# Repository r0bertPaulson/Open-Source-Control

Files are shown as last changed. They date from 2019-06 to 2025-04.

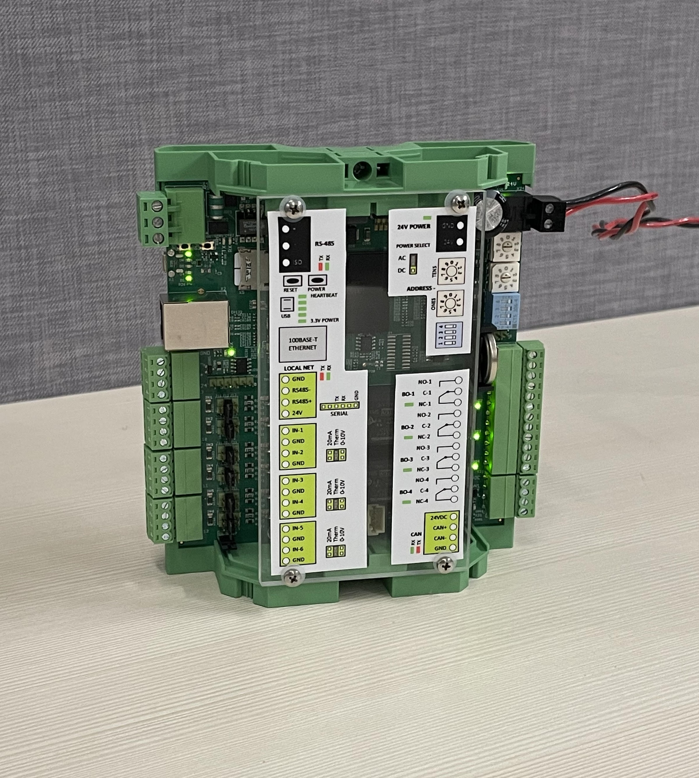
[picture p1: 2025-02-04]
Version_3.0/Open_Source_Controller_C663x+.jpg

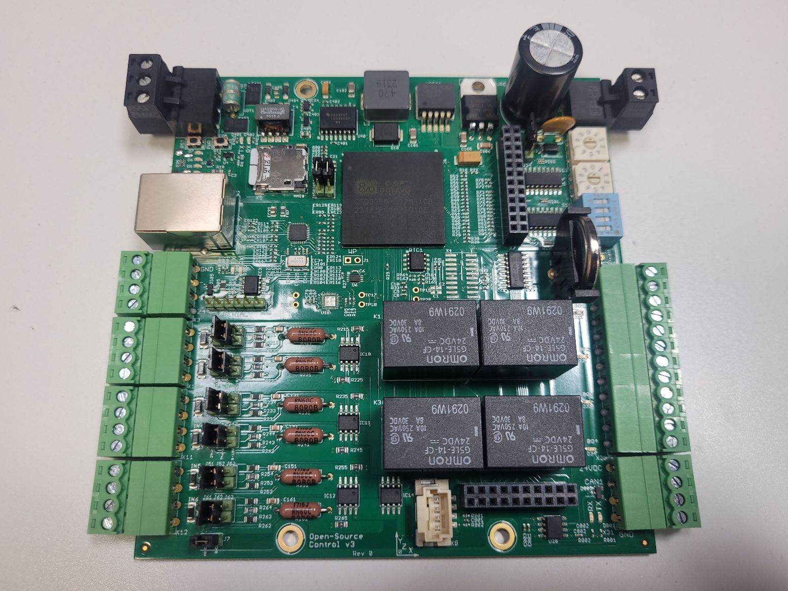
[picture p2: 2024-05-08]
Version_3.0/Open Source Controller V3.jpg

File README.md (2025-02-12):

# Open-Source-Control
Collection of Open Source IoT Designs

-Unitary Controller Version 3.0 - This device will be suitable for control of automated and networked building equipment at the unitary level. For example, you could control a single airconditioner unit with this device.

Project Status:
1.	Use Version 3.0 - Full BOM and Academic Free License statement to be posted here shortly.

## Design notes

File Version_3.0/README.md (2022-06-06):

New Modular Board which allows the creation of a family of devices to cover most Building Automation control use cases. 

This board will have headers that can connect to an add-on sub-board and other devices that are application specific.

For example, by adding an airflow sensor and two analog actuator outputs, you will have a device that can control a VAV (Variable Air Volume) terminal unit specifically.

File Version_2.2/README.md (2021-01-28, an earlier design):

Low Scale Prototype/Pre-Production Version. Minor hardware changes to occur as software dictates.

Adding the ability to connect main RS-485 tx/rx to either UART4 or PRU1_UART0. The PRU UART0 would be good to offload communication overhead of token-based network protocols from the main processor. Cleaning up layout and power planes for improved signal integrity.

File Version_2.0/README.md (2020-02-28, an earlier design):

DO NOT USE THIS DESIGN EITHER. FOR REFERENCE ONLY.

Prototype was made and tested. Board was mostly functional, but improvements and fixes have been made in 2.1+

Please Use Version 2.1+

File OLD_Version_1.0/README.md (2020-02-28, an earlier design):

DO NOT USE THIS DESIGN. PROTOTYPE HAS NOT BEEN MADE OR TESTED. FOR REFERENCE ONLY. 

Please Use Version 2.1+

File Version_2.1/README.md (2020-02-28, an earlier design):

Version 2.1

Testing shows that boards 2.1 and above are largely functional and are recommend for prototyping. Version 2.0 and below should not be used or built and are for reference only.

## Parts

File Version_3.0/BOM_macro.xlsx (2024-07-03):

Designator | Value | Footprint | Populate | MPN | Manufacturer | MPN | Manufacturer
C1 | DNI | C0603 | 0
C10 | 0.1uF, 6.3V | C0402 | 1 | GRM155R70J104KA01D | Murata
C100 | 1000uF, 50V, UHE1H102MHD6 | PCAP_16X25-THRU-ELECT | 0 | UHE1H102MHD6 | Nichicon
C101 | 0.47uF, 100V, X7R | 1206 | 1 | HMK316B7474KL-T | Taiyo Yuden
C102 | 0.47uF, 100V, X7R | 1206 | 1 | HMK316B7474KL-T | Taiyo Yuden
C104 | 0.1uF, 6.3V | C0402 | 1 | GRM155R70J104KA01D | Murata
C105 | 0.47uF, 100V, X7R | 1206 | 1 | HMK316B7474KL-T | Taiyo Yuden
C106 | 0.1uF, 50V | 1206 | 1 | C1206C104J5RACTU | KEMET
C11 | 220uF, 6.3V, T491C227K006AT | C/6032-28R | 1 | T491C227K006AT | KEMET
C111 | 1uF | C0805 | 1 | MF-CAP-0805-1uF | MacroFab
C121 | 1uF | C0805 | 1 | MF-CAP-0805-1uF | MacroFab
C131 | 1uF | C0805 | 1 | MF-CAP-0805-1uF | MacroFab
C14 | 0.1uF, 6.3V | C0402 | 1 | GRM155R70J104KA01D | Murata
C141 | 1uF | C0805 | 1 | MF-CAP-0805-1uF | MacroFab
C15 | 0.1uF, 6.3V | C0402 | 1 | GRM155R70J104KA01D | Murata
C151 | 1uF | C0805 | 1 | MF-CAP-0805-1uF | MacroFab
C161 | 1uF | C0805 | 1 | MF-CAP-0805-1uF | MacroFab
C2 | DNI | C0603 | 0
C21 | 10uF, 10V | C0805 | 1 | LMK212BJ106KG-T | Taiyo Yuden
C22 | 0.1uF, 6.3V | C0402 | 1 | GRM155R70J104KA01D | Murata
C3 | 0.1uF, 6.3V | C0402 | 1 | GRM155R70J104KA01D | Murata
C301 | 0.1uF, 6.3V | C0402 | 1 | GRM155R70J104KA01D | Murata
C4 | 47uF | C0805 | 1 | GRT21BR60J476ME13L | Murata
C401 | 0.1uF, 16V | C0402 | 1 | MF-CAP-0402-0.1uF | MacroFab
C402 | 0.1uF, 16V | C0402 | 1 | MF-CAP-0402-0.1uF | MacroFab
C403 | 0.1uF, 16V | C0402 | 1 | MF-CAP-0402-0.1uF | MacroFab
C404 | 10uF, 16V | C0805 | 1 | C0805C106K4PACTU | KEMET
C405 | 10uF, 16V | C0805 | 1 | C0805C106K4PACTU | KEMET
C406 | 4.7uF, 16V, T491A475K016AT | A/3216-18R | 1 | T491A475K016AT | KEMET
C6 | 0.1uF, 6.3V | C0402 | 1 | GRM155R70J104KA01D | Murata
C79 | 0.1uF, 6.3V | C0402 | 1 | GRM155R70J104KA01D | Murata
C8 | 1nF | C0402 | 1 | MF-CAP-0402-1nF | MacroFab
C801 | 0.1uF, 6.3V | C0402 | 1 | GRM155R70J104KA01D | Murata
C802 | 0.1uF, 6.3V | C0402 | 1 | GRM155R70J104KA01D | Murata
C803 | 4.7uF, 6.3V | C0402 | 1 | GRM155R60J475ME47D | Murata
C85 | 2200pF, 6.3V | C0402 | 1 | C0402C222K9RAC7867 | KEMET
C87 | 2200pF, 6.3V | C0402 | 1 | C0402C222K9RAC7867 | KEMET
C88 | 2200pF, 6.3V | C0402 | 1 | C0402C222K9RAC7867 | KEMET
C9 | 0.1uF, 6.3V | C0402 | 1 | GRM155R70J104KA01D | Murata
C901 | 0.1uF, 6.3V | C0402 | 1 | GRM155R70J104KA01D | Murata
D1 | LTST-C191KGKT | EIA-STD | 1 | LTST-C191KGKT | Lite-On
D18 | B550C-13-F | SMC | 1 | B550C-13-F | Diodes Inc.
D19 | LTST-C191KGKT | EIA-STD | 1 | LTST-C191KGKT | Lite-On
D3 | S1D | SMA | 1 | S1D | onsemi
D301 | LTST-C191KRKT | EIA-STD | 1 | LTST-C191KRKT | Lite-On
D302 | LTST-C191KGKT | EIA-STD | 1 | LTST-C191KGKT | Lite-On
D305 | SM712 | SOT23-3 | 1 | SM712-02HTG | Littelfuse
D31 | LTST-C191KGKT | EIA-STD | 1 | LTST-C191KGKT | Lite-On
D32 | LTST-C191KGKT | EIA-STD | 1 | LTST-C191KGKT | Lite-On
D33 | LTST-C191KGKT | EIA-STD | 1 | LTST-C191KGKT | Lite-On
D34 | LTST-C191KGKT | EIA-STD | 1 | LTST-C191KGKT | Lite-On
D4 | LTST-C191KGKT | EIA-STD | 1 | LTST-C191KGKT | Lite-On
D401 | LTST-C191KRKT | EIA-STD | 1 | LTST-C191KRKT | Lite-On
D402 | LTST-C191KGKT | EIA-STD | 1 | LTST-C191KGKT | Lite-On
D403 | MBR0520LT | SOD123 | 1 | MBR0520LT1G | onsemi
D404 | MBR0520LT | SOD123 | 1 | MBR0520LT1G | onsemi
D405 | SM712 | SOT23-3 | 1 | SM712-02HTG | Littelfuse
D5 | LTST-C191KGKT | EIA-STD | 1 | LTST-C191KGKT | Lite-On
D6 | LTST-C191KGKT | EIA-STD | 1 | LTST-C191KGKT | Lite-On
D7 | LTST-C191KGKT | EIA-STD | 1 | LTST-C191KGKT | Lite-On
D801 | LTST-C191KRKT | EIA-STD | 1 | LTST-C191KRKT | Lite-On
D802 | LTST-C191KGKT | EIA-STD | 1 | LTST-C191KGKT | Lite-On
D805 | CDSOT23-T24CAN | SOT23-3 | 1 | CDSOT23-T24CAN | Bourns
EC30 | 0.1uF, 6.3V | C0402 | 1 | GRM155R70J104KA01D | Murata
EC31 | 0.1uF, 6.3V | C0402 | 1 | GRM155R70J104KA01D | Murata
EC32 | 10uF, 10V | C0805 | 1 | LMK212BJ106KG-T | Taiyo Yuden
EC33 | 1uF, 10V | C0402 | 1 | C0402C105K8PACTU | KEMET
EC34 | 0.1uF, 6.3V | C0402 | 1 | GRM155R70J104KA01D | Murata
EC35 | 470pF, 6.3V | C0402 | 1 | C0402C471K9RACTU | KEMET
EC36 | 15pF, DNI | C0402 | 0
EC37 | 15pF, DNI | C0402 | 0
EC38 | 15pF, DNI | C0402 | 0
EC39 | 15pF, DNI | C0402 | 0
EC40 | 0.022uF, 10V | C0402 | 1 | C0402C223K8PACTU | KEMET
EC41 | 30pF, 50V | C0402 | 1 | GJM1555C1H300FB01D | Murata
EC42 | 30pF, 50V | C0402 | 1 | GJM1555C1H300FB01D | Murata
ER100 | 1.5K, 1% | R0402 | 1 | ERJPA2F1501X | Panasonic
ER101 | 10K, 1% | R0402 | 1 | RC0402FR-0710KL | Yageo
ER102 | 10K, 1% | R0402 | 1 | RC0402FR-0710KL | Yageo
ER103 | 10K, 1% | R0402 | 1 | RC0402FR-0710KL | Yageo
ER104 | 10K, 1% | R0402 | 1 | RC0402FR-0710KL | Yageo
ER105 | 1.5K, 1% | R0402 | 1 | ERJPA2F1501X | Panasonic
ER106 | 49.9, 1% | R0402 | 1 | RC0402FR-0749R9L | Yageo
ER107 | 49.9, 1% | R0402 | 1 | RC0402FR-0749R9L | Yageo
ER108 | 49.9, 1% | R0402 | 1 | RC0402FR-0749R9L | Yageo
ER109 | 49.9, 1% | R0402 | 1 | RC0402FR-0749R9L | Yageo
ER110 | 100, 1% | R0402 | 1 | RC0402FR-07100RL | Yageo
ER111 | 100, 1% | R0402 | 1 | RC0402FR-07100RL | Yageo
ER112 | 100, 1% | R0402 | 1 | RC0402FR-07100RL | Yageo
ER113 | 100, 1% | R0402 | 1 | RC0402FR-07100RL | Yageo
ER114 | 100, 1% | R0402 | 1 | RC0402FR-07100RL | Yageo
ER115 | 470, 1% | R0402 | 1 | RC0402FR-13470RL | Yageo
ER116 | 100, 1% | R0402 | 1 | RC0402FR-07100RL | Yageo
ER117 | 470, 1% | R0402 | 1 | RC0402FR-13470RL | Yageo
ER118 | 100, 1% | R0402 | 1 | RC0402FR-07100RL | Yageo
ER119 | 100, 1% | R0402 | 1 | RC0402FR-07100RL | Yageo
ER120 | 10K, 1% | R0402 | 1 | RC0402FR-0710KL | Yageo
ER122 | 0, 1% | R0402 | 1 | RC0402FR-070RL | Yageo
ER123 | 100, 1% | R0402 | 1 | RC0402FR-07100RL | Yageo
ER124 | 100, 1% | R0402 | 1 | RC0402FR-07100RL | Yageo
ER125 | 1M, 1%, DNI | R0402 | 0
ER126 | 0, 1% | R0402 | 1 | RC0402FR-070RL | Yageo
ER127 | 10, 1% | R0402 | 1 | RC0402FR-0710RL | Yageo
ER128 | 12.1K, 1% | R0402 | 1 | ERJ-2RKF1212X | Panasonic
ER129 | 10K, 1% | R0402 | 1 | RC0402FR-0710KL | Yageo
ER98 | 1.5K, 1% | R0402 | 1 | ERJPA2F1501X | Panasonic
ER99 | 1.5K, 1% | R0402 | 1 | ERJPA2F1501X | Panasonic
F1 | 60V, 750mA, R075 | PTH | 0 | MF-R075-99 | Bourns
F401 | TBU-CA085-300-WH | TBU-CA | 1 | TBU-CA085-300-WH | Bourns
F402 | TBU-CA085-300-WH | TBU-CA | 1 | TBU-CA085-300-WH | Bourns
FB7 | 150ohm, 800mA | C0805 | 1 | MU2029-151Y | Bourns
FUD1 | FIDUCIAL | FIDUCIAL_40MIL | 0
FUD2 | FIDUCIAL | FIDUCIAL_40MIL | 0
FUD3 | FIDUCIAL | FIDUCIAL_40MIL | 0
FUD4 | FIDUCIAL | FIDUCIAL_40MIL | 0
FUD5 | FIDUCIAL | FIDUCIAL_40MIL | 0
FUD6 | FIDUCIAL | FIDUCIAL_40MIL | 0
G1 | CR2032V | CR2032V | 0
GDT1 | 2036-07-B3 | 2036-XX-B3 | 0 | 2036-07-B3 | Bourns
IC10 | MCP6002SMT | SOIC8 | 1 | MCP6002T-E/SN | Microchip
IC11 | MCP6002SMT | SOIC8 | 1 | MCP6002T-E/SN | Microchip
IC12 | MCP6002SMT | SOIC8 | 1 | MCP6002T-E/SN | Microchip
IC14 | MCP6002SMT | SOIC8 | 1 | MCP6002T-E/SN | Microchip
IC2 | ULN2003AD | SO16 | 1 | ULN2003AD | Texas Instruments
IC4 | 74HC165D | SO16 | 1 | 74HC165D | Toshiba | SN74HC165DR | Texas Instruments
IC5 | 74HC165D | SO16 | 1 | 74HC165D | Toshiba | SN74HC165DR | Texas Instruments
J1 |  | H2-2.54 | 0
J11 |  | H2-2.54 | 0
J12 |  | H2-2.54 | 0
J13 |  | H2-2.54 | 0
J21 |  | H2-2.54 | 0
J22 |  | H2-2.54 | 0
J23 |  | H2-2.54 | 0
J24 | 6p-2.54 | H3-2.54 | 0 | P125-1106A1BS116A1 | YXCON
J3 |  | H2-2.54 | 0
J31 |  | H2-2.54 | 0
J32 |  | H2-2.54 | 0
J33 |  | H2-2.54 | 0
J41 |  | H2-2.54 | 0
J42 |  | H2-2.54 | 0
J43 |  | H2-2.54 | 0
J45 |  | H2-2.54 | 0
J450 |  | H2-2.54 | 0
J454 |  | H2-2.54 | 0
J51 |  | H2-2.54 | 0
J52 |  | H2-2.54 | 0
J53 |  | H2-2.54 | 0
J61 |  | H2-2.54 | 0
J62 |  | H2-2.54 | 0
J63 |  | H2-2.54 | 0
J7 |  | H2-2.54 | 0
K1 | G5LE-14-CF DC24 | JS-M | 0 | G5LE-14-CF DC24 | Omron
K2 | G5LE-14-CF DC24 | JS-M | 0 | G5LE-14-CF DC24 | Omron
K3 | G5LE-14-CF DC24 | JS-M | 0 | G5LE-14-CF DC24 | Omron
K4 | G5LE-14-CF DC24 | JS-M | 0 | G5LE-14-CF DC24 | Omron
L2 | SRP1265A-470M | SRP1265 | 1 | SRP1265A-470M | Bourns
MTG1 | MOUNT-PAD-ROUND3.6 | 3,6-PAD | 0
MTG2 | MOUNT-PAD-ROUND3.6 | 3,6-PAD | 0
MTG3 | MOUNT-PAD-ROUND3.6 | 3,6-PAD | 0
MTG4 | MOUNT-PAD-ROUND3.6 | 3,6-PAD | 0
Q1 | MMBT2907 | SOT23-BEC | 1 | MMBT2907ALT1G | onsemi
R10 | 0, 1% | R0805 | 1 | ERJ-6GEY0R00V | Panasonic
R11 | 0 | R0402 | 1 | MF-RES-0402-0 | MacroFab
R12 | 1.5K, 1% | R0402 | 1 | ERJPA2F1501X | Panasonic
R13 | 1.5K, 1% | R0402 | 1 | ERJPA2F1501X | Panasonic
R15 | 40.2K | R0402 | 1 | RC0402FR-0740K2L | Yageo
R163 | 100K, DNI | R0402 | 0
R164 | 1.5K, 1% | R0402 | 1 | ERJPA2F1501X | Panasonic
R168 | 10K | R0402 | 1 | MF-RES-0402-10K | MacroFab
R169 | 10K, 1% | R0402 | 1 | RC0402FR-0710KL | Yageo
R170 | 10K, 1% | R0402 | 1 | RC0402FR-0710KL | Yageo
R171 | 10K | R0402 | 1 | MF-RES-0402-10K | MacroFab
R172 | 10K | R0402 | 1 | MF-RES-0402-10K | MacroFab
R173 | 10K | R0402 | 1 | MF-RES-0402-10K | MacroFab
R174 | 10K | R0402 | 1 | MF-RES-0402-10K | MacroFab
R18 | 4.75K, 1% | R0402 | 1 | RC0402FR-074K75L | Yageo
R181 | B72520T0300K062 | CT/CN1206 | 1 | B72520T0300K062 | EPCOS
R182 | B72520T0300K062 | CT/CN1206 | 1 | B72520T0300K062 | EPCOS
R183 | B72520T0300K062 | CT/CN1206 | 1 | B72520T0300K062 | EPCOS
R184 | B72520T0300K062 | CT/CN1206 | 1 | B72520T0300K062 | EPCOS
R185 | B72520T0300K062 | CT/CN1206 | 1 | B72520T0300K062 | EPCOS
R186 | B72520T0300K062 | CT/CN1206 | 1 | B72520T0300K062 | EPCOS
R20 | 10K | R0402 | 1 | MF-RES-0402-10K | MacroFab
R21 | 499 | R0402 | 1 | RC0402FR-07499RL | Yageo
R211 | 80, 0.1% | 0309/12 | 0 | CMF6080R000BEBF | Vishay
R212 | 10K, 1% | R0805 | 1 | CRCW080510K0FKEB | Vishay
R213 | 2K, 1% | R0805 | 1 | ERJ-6ENF2001V | Panasonic
R214 | 10K, 1% | R0805 | 1 | CRCW080510K0FKEB | Vishay
R215 | 100K | R0805 | 1 | MF-RES-0805-100K | MacroFab
R22 | 4.75K, 1% | R0402 | 1 | RC0402FR-074K75L | Yageo
R221 | 80, 0.1% | 0309/12 | 0 | CMF6080R000BEBF | Vishay
R222 | 10K, 1% | R0805 | 1 | CRCW080510K0FKEB | Vishay
R223 | 2K, 1% | R0805 | 1 | ERJ-6ENF2001V | Panasonic
R224 | 10K, 1% | R0805 | 1 | CRCW080510K0FKEB | Vishay
R225 | 100K | R0805 | 1 | MF-RES-0805-100K | MacroFab
R231 | 80, 0.1% | 0309/12 | 0 | CMF6080R000BEBF | Vishay
R232 | 10K, 1% | R0805 | 1 | CRCW080510K0FKEB | Vishay
R233 | 2K, 1% | R0805 | 1 | ERJ-6ENF2001V | Panasonic
R234 | 10K, 1% | R0805 | 1 | CRCW080510K0FKEB | Vishay
R235 | 100K | R0805 | 1 | MF-RES-0805-100K | MacroFab
R241 | 80, 0.1% | 0309/12 | 0 | CMF6080R000BEBF | Vishay
R242 | 10K, 1% | R0805 | 1 | CRCW080510K0FKEB | Vishay
R243 | 2K, 1% | R0805 | 1 | ERJ-6ENF2001V | Panasonic
R244 | 10K, 1% | R0805 | 1 | CRCW080510K0FKEB | Vishay
R245 | 100K | R0805 | 1 | MF-RES-0805-100K | MacroFab
R25 | 0, 1% | R0402 | 1 | RC0402FR-070RL | Yageo
R251 | 80, 0.1% | 0309/12 | 0 | CMF6080R000BEBF | Vishay
R252 | 10K, 1% | R0805 | 1 | CRCW080510K0FKEB | Vishay
R253 | 2K, 1% | R0805 | 1 | ERJ-6ENF2001V | Panasonic
R254 | 10K, 1% | R0805 | 1 | CRCW080510K0FKEB | Vishay
R255 | 100K | R0805 | 1 | MF-RES-0805-100K | MacroFab
R26 | 1.5K, 1% | R0402 | 1 | ERJPA2F1501X | Panasonic
R261 | 80, 0.1% | 0309/12 | 0 | CMF6080R000BEBF | Vishay
R262 | 10K, 1% | R0805 | 1 | CRCW080510K0FKEB | Vishay
R263 | 2K, 1% | R0805 | 1 | ERJ-6ENF2001V | Panasonic
R264 | 10K, 1% | R0805 | 1 | CRCW080510K0FKEB | Vishay
R265 | 100K | R0805 | 1 | MF-RES-0805-100K | MacroFab
R27 | 100K, 1% | R0402 | 1 | RC0402FR-07100KL | Yageo
R28 | 0, 1% | R0402 | 1 | RC0402FR-070RL | Yageo
R281 | 10K | RN0804 | 1 | YC124-JR-0710KL | Yageo
R282 | 10K | RN0804 | 1 | YC124-JR-0710KL | Yageo
R29 | 0, 1% | R0402 | 1 | RC0402FR-070RL | Yageo
R291 | 10K | RN0804 | 1 | YC124-JR-0710KL | Yageo
R3 | 0, 1% | R0402 | 1 | RC0402FR-070RL | Yageo
R30 | 0, 1% | R0402 | 1 | RC0402FR-070RL | Yageo
R301 | 1K | R0402 | 1 | MF-RES-0402-1K | MacroFab
R302 | 1K | R0402 | 1 | MF-RES-0402-1K | MacroFab
R303 | 1K, DNI | R0402 | 0
R304 | 1K, DNI | R0402 | 0
R305 | 150, 1% | R0805 | 1 | CRCW0805150RFKEAHP | Vishay
R31 | 22, 1% | R0402 | 1 | RC0402FR-0722RL | Yageo
R33 | 0, 1% | R0402 | 1 | RC0402FR-070RL | Yageo
R34 | .1, 0805 | R0805 | 1 | CRL0805-FW-R100ELF | Bourns
R35 | 1K | RN0804 | 1 | YC124-JR-071KL | Yageo
R39 | 4.75K, 1% | R0402 | 1 | RC0402FR-074K75L | Yageo
R4 | 0, 1% | R0402 | 1 | RC0402FR-070RL | Yageo
R40 | 4.75K, 1% | R0402 | 1 | RC0402FR-074K75L | Yageo
R401 | 1K | R0402 | 1 | MF-RES-0402-1K | MacroFab
R402 | 1K | R0402 | 1 | MF-RES-0402-1K | MacroFab
R41 | 4.75K, 1% | R0402 | 1 | RC0402FR-074K75L | Yageo
R5 | 0 | R0402 | 1 | MF-RES-0402-0 | MacroFab
R53 | 100K, 1% | R0402 | 1 | RC0402FR-07100KL | Yageo
R54 | 100K, 1%, DNI | R0402 | 0
R55 | 100K, 1% | R0402 | 1 | RC0402FR-07100KL | Yageo
R56 | 100K, 1% | R0402 | 1 | RC0402FR-07100KL | Yageo
R57 | 100K, 1% | R0402 | 1 | RC0402FR-07100KL | Yageo
R58 | 100K, 1% | R0402 | 1 | RC0402FR-07100KL | Yageo
R59 | 100K, 1% | R0402 | 1 | RC0402FR-07100KL | Yageo
R6 | 100K, DNI | R0402 | 0
R60 | 100K, 1% | R0402 | 1 | RC0402FR-07100KL | Yageo
R61 | 100K, 1% | R0402 | 1 | RC0402FR-07100KL | Yageo
R62 | 100K, 1% | R0402 | 1 | RC0402FR-07100KL | Yageo
R63 | 100K, 1% | R0402 | 1 | RC0402FR-07100KL | Yageo
R64 | 100K, 1%, DNI | R0402 | 0
R65 | 100K, 1%, DNI | R0402 | 0
R66 | 100K, 1%, DNI | R0402 | 0
R67 | 100K, 1% | R0402 | 1 | RC0402FR-07100KL | Yageo
R68 | 100K, 1% | R0402 | 1 | RC0402FR-07100KL | Yageo
R69 | 100, 1% | R0402 | 1 | RC0402FR-07100RL | Yageo
R70 | 100K, 1%, DNI | R0402 | 0
R71 | 100K, 1% | R0402 | 1 | RC0402FR-07100KL | Yageo
R72 | 100K, 1%, DNI | R0402 | 0
R73 | 100K, 1%, DNI | R0402 | 0
R74 | 100K, 1%, DNI | R0402 | 0
R75 | 100K, 1%, DNI | R0402 | 0
R76 | 100K, 1%, DNI | R0402 | 0
R77 | 100K, 1%, DNI | R0402 | 0
R78 | 100K, 1%, DNI | R0402 | 0
R79 | 100K, 1%, DNI | R0402 | 0
R8 | 1K | R0402 | 1 | MF-RES-0402-1K | MacroFab
R80 | 100K, 1%, DNI | R0402 | 0
R801 | 1K | R0402 | 1 | MF-RES-0402-1K | MacroFab
R802 | 1K | R0402 | 1 | MF-RES-0402-1K | MacroFab
R81 | 100K, 1% | R0402 | 1 | RC0402FR-07100KL | Yageo
R82 | 100K, 1% | R0402 | 1 | RC0402FR-07100KL | Yageo
R83 | 100K, 1% | R0402 | 1 | RC0402FR-07100KL | Yageo
R84 | 100K, 1%, DNI | R0402 | 0
R85 | 100K, 1%, DNI | R0402 | 0
R86 | 10K, 1% | R0402 | 1 | RC0402FR-0710KL | Yageo
R87 | 10K, 1% | R0402 | 1 | RC0402FR-0710KL | Yageo
R88 | 10K, 1% | R0402 | 1 | RC0402FR-0710KL | Yageo
R89 | 10K, 1% | R0402 | 1 | RC0402FR-0710KL | Yageo
R90 | 10K, 1% | R0402 | 1 | RC0402FR-0710KL | Yageo
R901 | 1.5K, 1% DNI | R0402 | 0
R902 | 1.5K, 1% DNI | R0402 | 0
R91 | 10K, 1% | R0402 | 1 | RC0402FR-0710KL | Yageo
R92 | 10K, 1% | R0402 | 1 | RC0402FR-0710KL | Yageo
RTC1 | DS3231MZ+ | SO08 | 1 | DS3231MZ+ | Analog Devices
S1 | KMR231GLFS | SW4SMD_63X161LS | 1 | KMR233GLFG | C&K Components
S11 |  | P101 | 1 | 94HAB10T | Grayhill
S12 |  | P101 | 1 | 94HAB10T | Grayhill
S13 |  | DS-04 | 1 | 206-4LPST | CTS Components
S2 | KMR231GLFS | SW4SMD_63X161LS | 1 | KMR233GLFG | C&K Components
T4 | DA2304-AL | DA230X-AL | 1 | DA2304-AL | Coilcraft
TP1 | TPB0,65 | TP_B0,65 | 0
TP10 | TESTPAD/W_HOLE_1X1 | TESTPAD/W_HOLE_1X1 | 0
TP11 | TPB0,65 | TP_B0,65 | 0
TP12 | TPB0,65 | TP_B0,65 | 0
TP13 | TPB0,65 | TP_B0,65 | 0
TP14 | TPB0,65 | TP_B0,65 | 0
TP15 | TPB0,65 | TP_B0,65 | 0
TP16 | TPB0,65 | TP_B0,65 | 0
TP17 | TESTPAD/W_HOLE_1X1 | TESTPAD/W_HOLE_1X1 | 0
TP18 | TESTPAD/W_HOLE_1X1 | TESTPAD/W_HOLE_1X1 | 0
TP19 | TESTPAD/W_HOLE_1X1 | TESTPAD/W_HOLE_1X1 | 0
TP2 | TPB0,65 | TP_B0,65 | 0
TP20 | TESTPAD/W_HOLE_1X1 | TESTPAD/W_HOLE_1X1 | 0
TP21 | TPB0,65 | TP_B0,65 | 0
TP22 | TPB0,65 | TP_B0,65 | 0
TP23 | TPB0,65 | TP_B0,65 | 0
TP24 | TPB0,65 | TP_B0,65 | 0
TP26 | TPB0,65 | TP_B0,65 | 0
TP3 | TPB0,65 | TP_B0,65 | 0
TP31 | TPB0,65 | TP_B0,65 | 0
TP32 | TPB0,65 | TP_B0,65 | 0
TP33 | TPB0,65 | TP_B0,65 | 0
TP4 | TPB0,65 | TP_B0,65 | 0
TP5 | TESTPAD/W_HOLE_1X1 | TESTPAD/W_HOLE_1X1 | 0
TP6 | TESTPAD/W_HOLE_1X1 | TESTPAD/W_HOLE_1X1 | 0
TP7 | TESTPAD/W_HOLE_1X1 | TESTPAD/W_HOLE_1X1 | 0
TP8 | TESTPAD/W_HOLE_1X1 | TESTPAD/W_HOLE_1X1 | 0
TP9 | TESTPAD/W_HOLE_1X1 | TESTPAD/W_HOLE_1X1 | 0
U$2 |  | XYZ-LABEL | 0
U1 | OSD3358-512M-ICB | OSD335X-BGA-400 | 1 | OSD3358-512M-ICB | Octavo Systems
U16 | AT97SC3205T-G3M4400B | QFN32-0.4-4X4MM | 0 | AT97SC3205T-G3M4400B | Microchip
U2 | TPD4S012_DRY_6_P1_M | DRY6 | 1 | TPD4S012DRYR | Texas Instruments
U27 | LAN8710 | LAN8710A-QFN32 | 1 | LAN8710AI-EZK | Microchip
U28 | TCAN1051HV | BEAGLEBONE_BLUE_D8 | 1 | TCAN1051HVDR | Texas Instruments
U29 | MAX3483EESA+T | 21-0041B_8 | 1 | MAX3483EESA+T | Analog Devices
U4 | APX811-31UGSOT | SOT143-R | 1 | APX811-31UG-7 | Diodes Inc.
U40 | ISO3086TDW | DW16 | 1 | ISO3086TDW | Texas Instruments
U5 | TLVH431 | SOT23-3 | 1 | TLVH431IDBZR | Texas Instruments
U6 | SN74LVC2G241_DCU_8 | DCU8 | 1 | SN74LVC2G241DCUT | Texas Instruments
VREG1 | LM2596S-5.0 | TO263-5 | 1 | LM2596S-5.0 | Texas Instruments | LM2596S-5.0/NOPB | Texas Instruments
VREG2 | L7824CV | 78XXL | 1 | L7824CV-DG | STMicroelectronics
VREG4 | TPS76350 | DBV5 | 1 | TPS76350DBVR | Texas Instruments
X1 | 10118194-0001LF | 10118194-0001LF(MICRO-USB-B-AMPHENOL-FCI) | 1 | 10118194-0001LF | Amphenol Communications Solutions
X10 | MC4 | MC4 | 1 | ECH381R-04P | Dinkle
X11 | MC4 | MC4 | 1 | ECH381R-04P | Dinkle
X12 | MC4 | MC4 | 1 | ECH381R-04P | Dinkle
X2 | J0011D01BNL | J0011D01BNL | 1 | J0011D01BNL | Pulse
X21 | MC12 | MC12 | 1 | ECH381R-12P | Dinkle
X24 | MSTBA2 | MSTBA2 | 1 | 2EHDRC-02P-BK | Dinkle | 2EHDRC-02P | Dinkle
X3 | MC4 | MC4 | 1 | ECH381R-04P | Dinkle
X31 | MC4 | MC4 | 1 | ECH381R-04P | Dinkle
X4 | CTI-JTAG | CTI-JTAG | 0
X41 | MSTBA3 | MSTBA3 | 1 | 2EHDRC-03P | Dinkle
X5 | DM3CS-SF | DM3CS-SF | 1 | DM3CS-SF | HIROSE ELECTRIC
X6 | 6p-2.54 | H6-2.54 | 0 | P125-1106A1BS116A1 | YXCON
X7 | TH-2X10 | H2X10-2.54 | 0
X8 | TH-2X10 | H2X10-2.54 | 0
X9 | 5600200420 | 5600200420 | 1 | 560020-0420 | Molex
Y7 | ECS-250-12-30-GN-TR | XTAL_2-SMD(5X3.2MM) | 1 | ECS-250-12-30-GN-TR | ECS International

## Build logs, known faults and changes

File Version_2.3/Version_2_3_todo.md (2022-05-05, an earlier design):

Version 2.3 To Do:

1) Create I2C connection for Sensirion Air Flow Sensor by adding Molex Plugable Terminal PN 5023520400
	or 5600200420 (vertical mount).
2) Create connection for Analog Output Add-On board.
3) Replace 5V Regulator Power Inductor (L2) with Bourns PN SRP1265A-470M. {DONE}
4) Find alternate compatible crystal for Ethernet Phy. ABM3-25.000MHZ-J2Y-T (also used for Micrel) 
	or alternatively use the direct replacement from Digikey ECS-250-12-30-GN-TR? {DONE}
5) Update Crystal Footprint and device (Y7) with generic 5x3.2mm 2-SMD {DONE}  
5) Change Relay Output terminal blocks to 12 position version with C, N.O. and N.C. terminals.
6) Add capability for add-on Relay HOA board.
7) Update Relay part number to G5LE due to JS1 EOL. {DONE}

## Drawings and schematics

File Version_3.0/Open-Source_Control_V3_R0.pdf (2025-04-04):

# Power & Reset

A

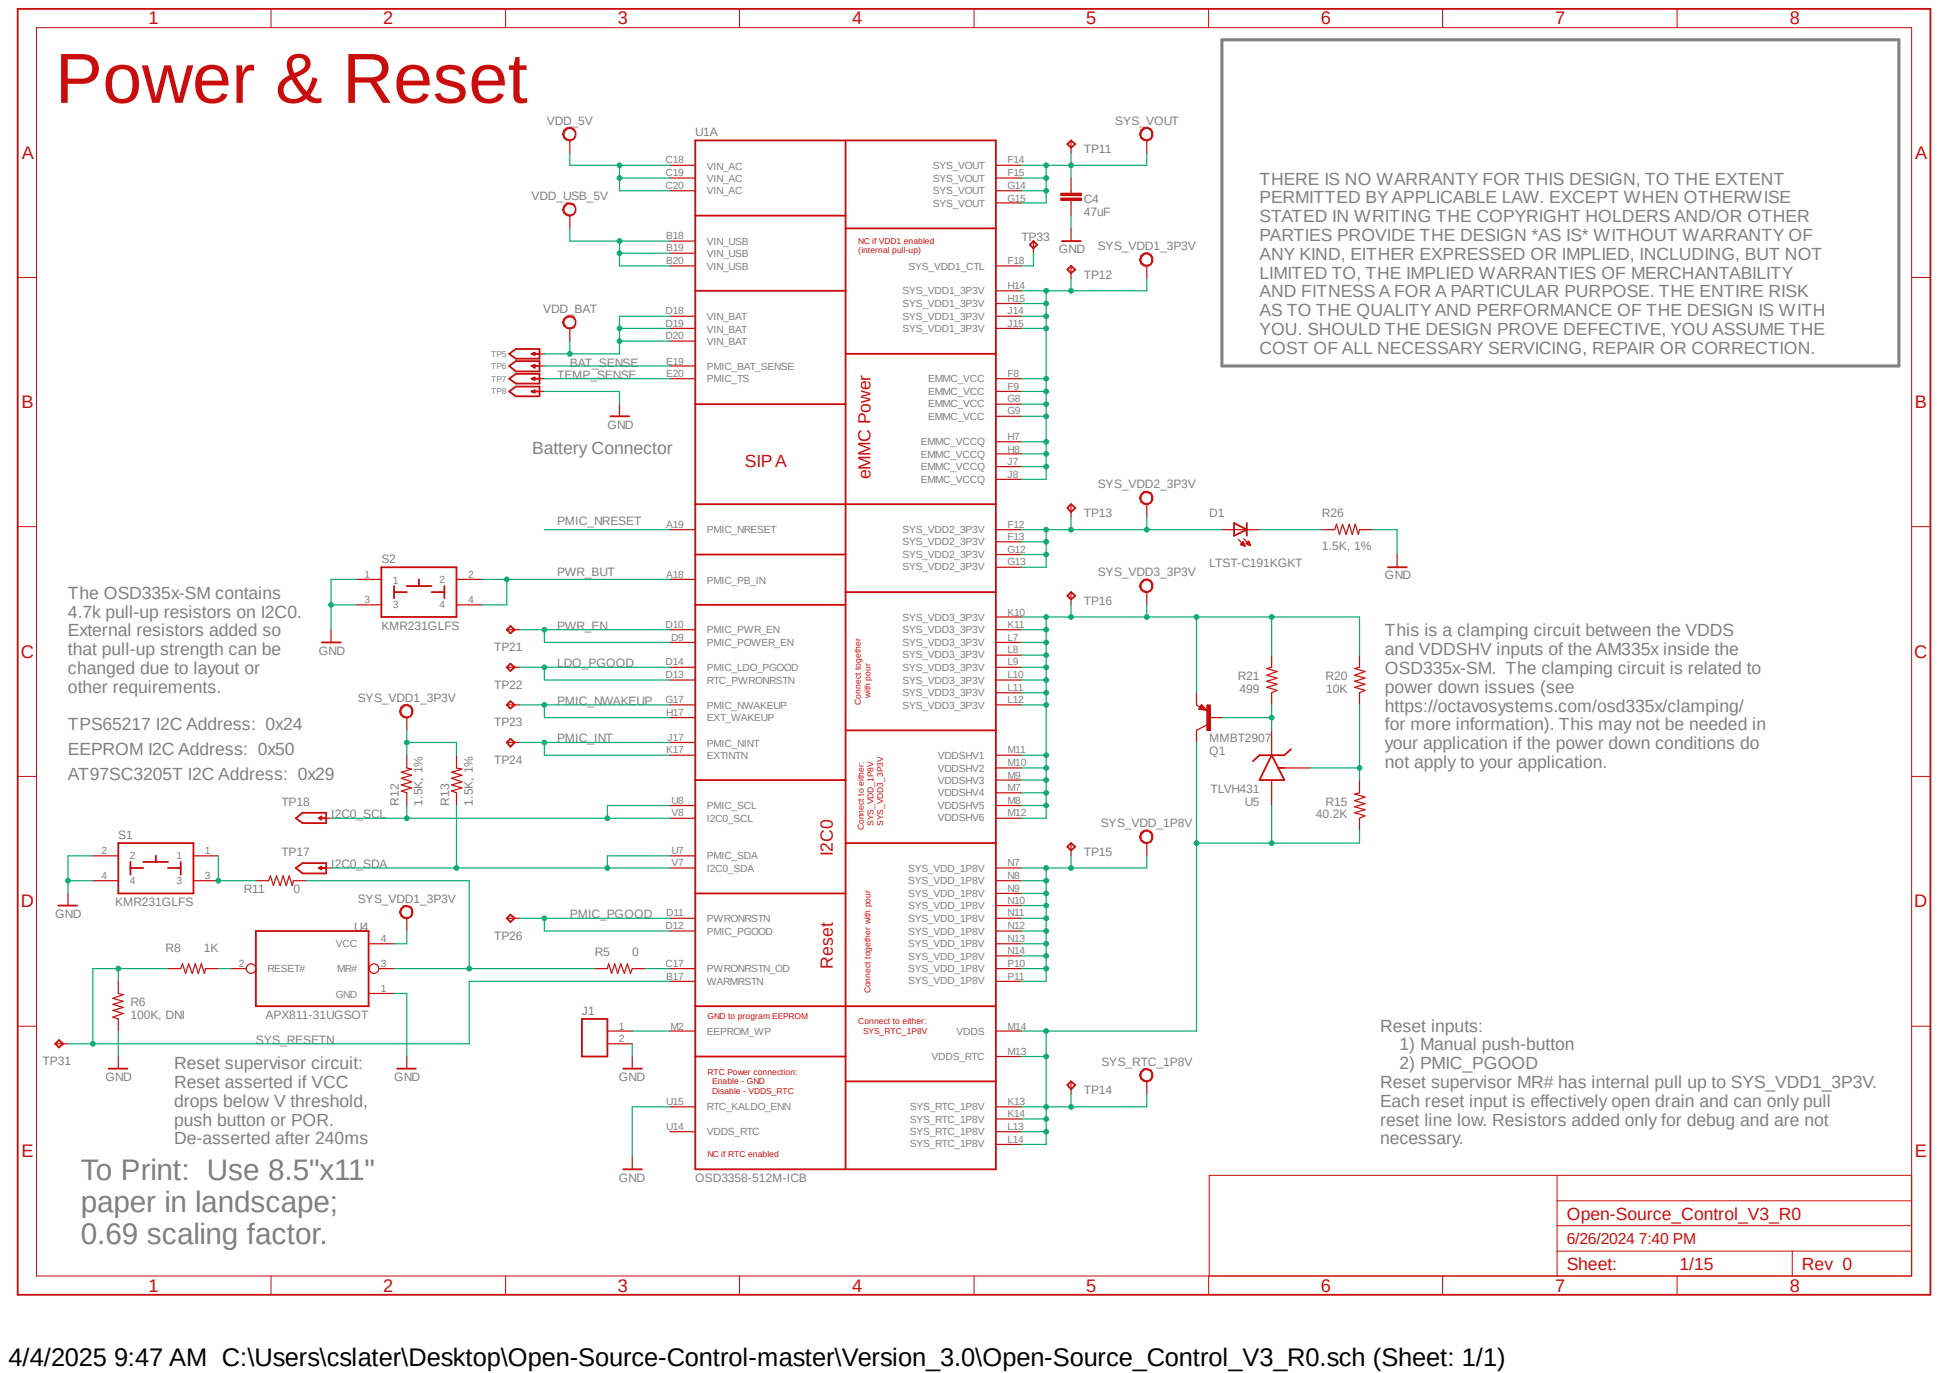
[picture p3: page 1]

THERE IS NO WARRANTY FOR THIS DESIGN, TO THE EXTENT
PERMITTED BY APPLICABLE LAW. EXCEPT WHEN OTHERWISE
STATED IN WRITING THE COPYRIGHT HOLDERS AND/OR OTHER
PARTIES PROVIDE THE DESIGN *AS IS* WITHOUT WARRANTY OF
ANY KIND, EITHER EXPRESSED OR IMPLIED, INCLUDING, BUT NOT
LIMITED TO, THE IMPLIED WARRANTIES OF MERCHANTABILITY
AND FITNESS A FOR A PARTICULAR PURPOSE. THE ENTIRE RISK
AS TO THE QUALITY AND PERFORMANCE OF THE DESIGN IS WITH
YOU. SHOULD THE DESIGN PROVE DEFECTIVE, YOU ASSUME THE
COST OF ALL NECESSARY SERVICING, REPAIR OR CORRECTION.

The OSD335x-SM contains
4.7k pull-up resistors on I2C0.
External resistors added so
that pull-up strength can be
changed due to layout or
other requirements.

This is a clamping circuit between the VDDS
and VDDSHV inputs of the AM335x inside the
OSD335x-SM. The clamping circuit is related to
power down issues (see
https://octavosystems.com/osd335x/clamping/
for more information). This may not be needed in
your application if the power down conditions do
not apply to your application.

Connect together with pour

GND to program EEPROM

Reset inputs:
1) Manual push-button
2) PMIC_PGOOD
Reset supervisor MR# has internal pull up to SYS_VDD1_3P3V.
Each reset input is effectively open drain and can only pull
reset line low. Resistors added only for debug and are not
necessary.

Reset supervisor circuit:
Reset asserted if VCC
drops below V threshold,
push button or POR.
De-asserted after 240ms

NC if RTC enabled

4/4/2025 9:47 AM C:\Users\cslater\Desktop\Open-Source-Control-master\Version_3.0\Open-Source_Control_V3_R0.sch (Sheet: 1/1)

# Clocks, Analog & USB

## SIP B

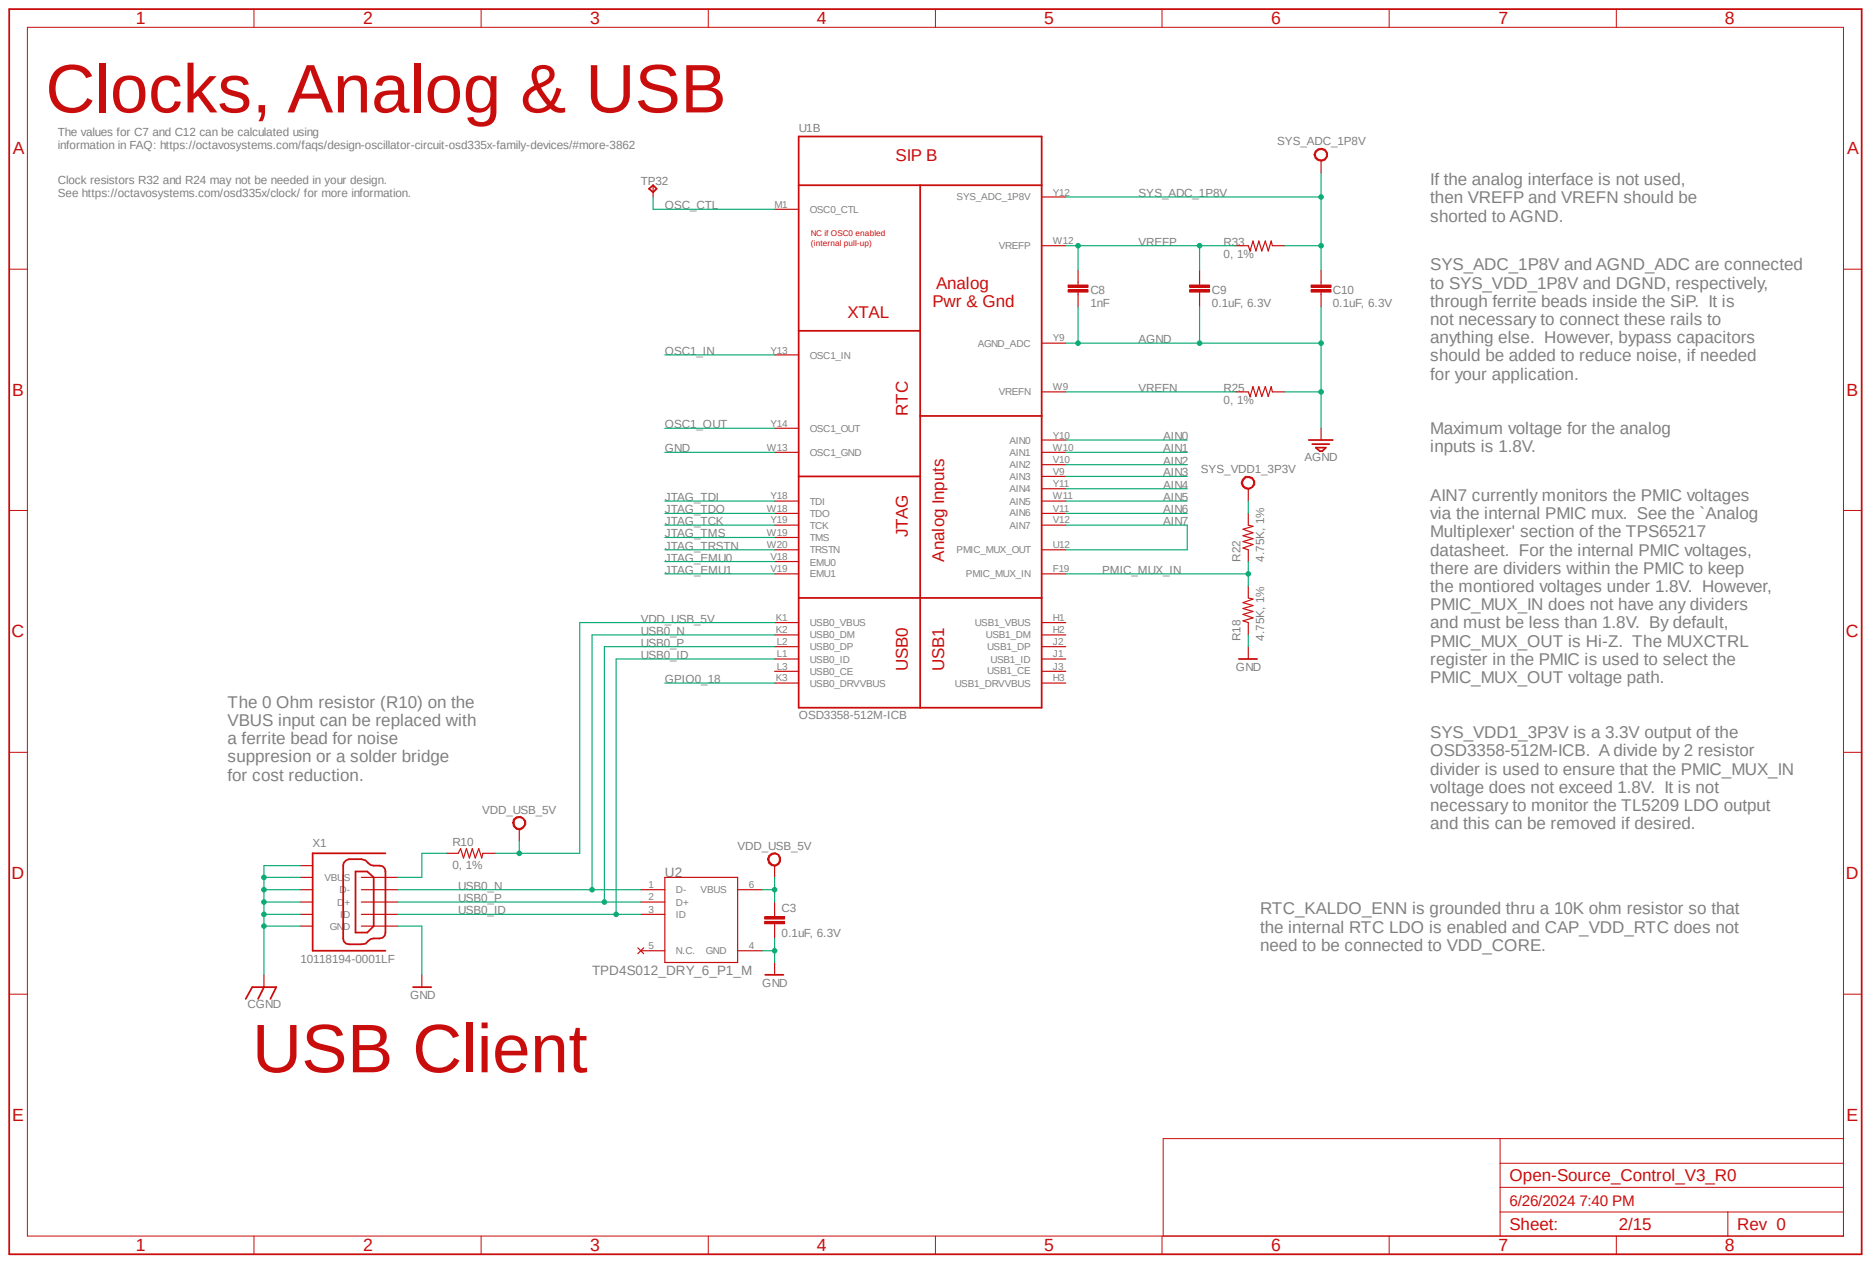
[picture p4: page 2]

The values for C7 and C12 can be calculated using
information in FAQ: https://octavosystems.com/faqs/design-oscillator-circuit-osd335x-family-devices/#more-3862

Clock resistors R32 and R24 may not be needed in your design.
See https://octavosystems.com/osd335x/clock/ for more information.

If the analog interface is not used,
then VREFP and VREFN should be
shorted to AGND.

SYS_ADC_1P8V and AGND_ADC are connected
to SYS_VDD_1P8V and DGND, respectively,
through ferrite beads inside the SiP. It is
not necessary to connect these rails to
anything else. However, bypass capacitors
should be added to reduce noise, if needed
for your application.

Maximum voltage for the analog
inputs is 1.8V.

AIN7 currently monitors the PMIC voltages
via the internal PMIC mux. See the `Analog
Multiplexer' section of the TPS65217
datasheet. For the internal PMIC voltages,
there are dividers within the PMIC to keep
the montiored voltages under 1.8V. However,
PMIC_MUX_IN does not have any dividers
and must be less than 1.8V. By default,
PMIC_MUX_OUT is Hi-Z. The MUXCTRL
register in the PMIC is used to select the
PMIC_MUX_OUT voltage path.

The 0 Ohm resistor (R10) on the
VBUS input can be replaced with
a ferrite bead for noise
suppresion or a solder bridge
for cost reduction.

SYS_VDD1_3P3V is a 3.3V output of the
OSD3358-512M-ICB. A divide by 2 resistor
divider is used to ensure that the PMIC_MUX_IN
voltage does not exceed 1.8V. It is not
necessary to monitor the TL5209 LDO output
and this can be removed if desired.

USB0_ID | C3 D+ ID 3

USB0_P | D+ 2

RTC_KALDO_ENN is grounded thru a 10K ohm resistor so that
the internal RTC LDO is enabled and CAP_VDD_RTC does not
need to be connected to VDD_CORE.

# SiP Interfaces

A

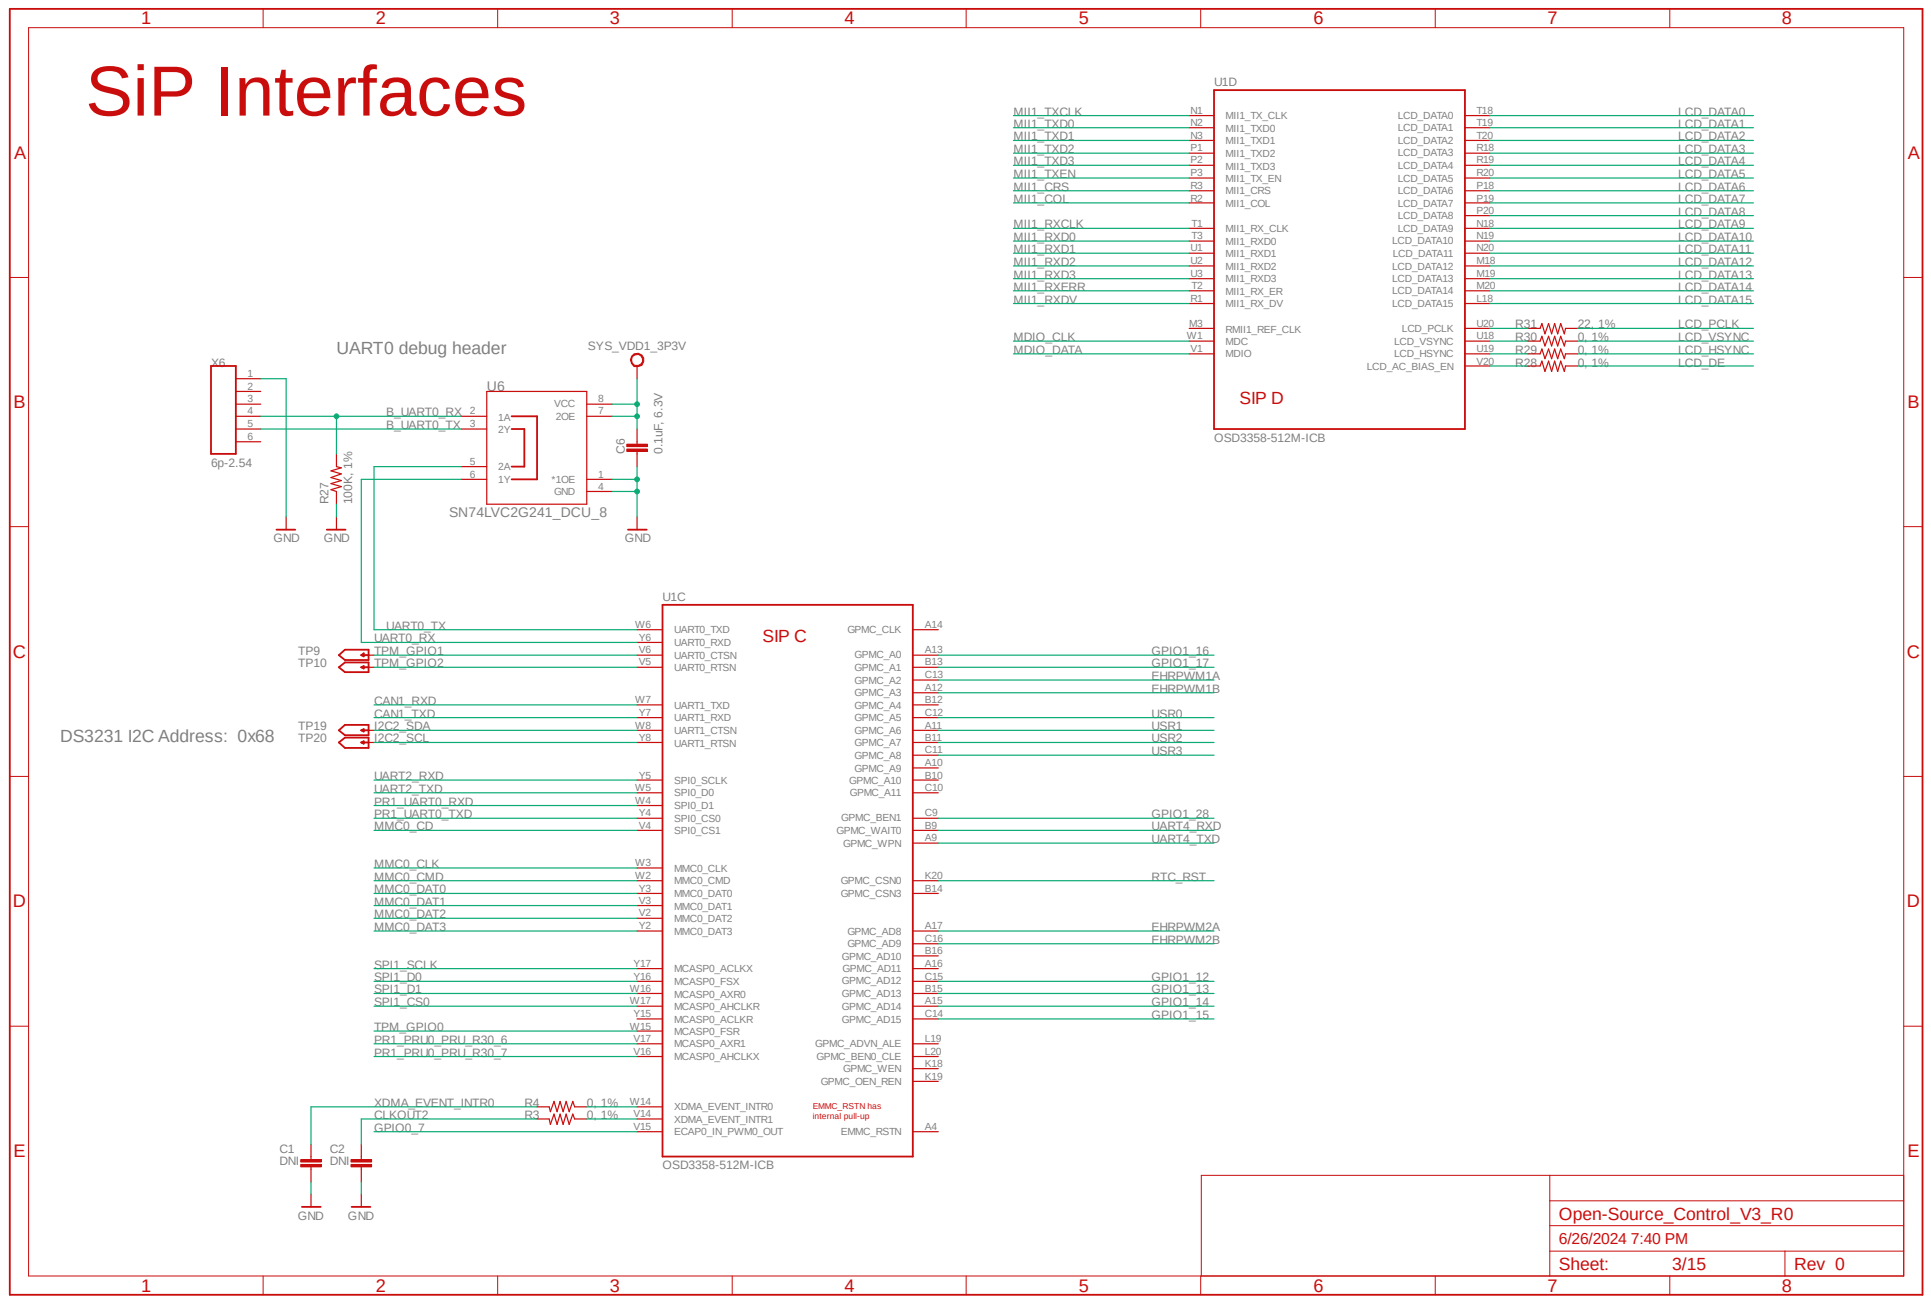
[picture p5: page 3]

5 | B_UART0_TX | 2Y 3
6 | | 2A 5
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

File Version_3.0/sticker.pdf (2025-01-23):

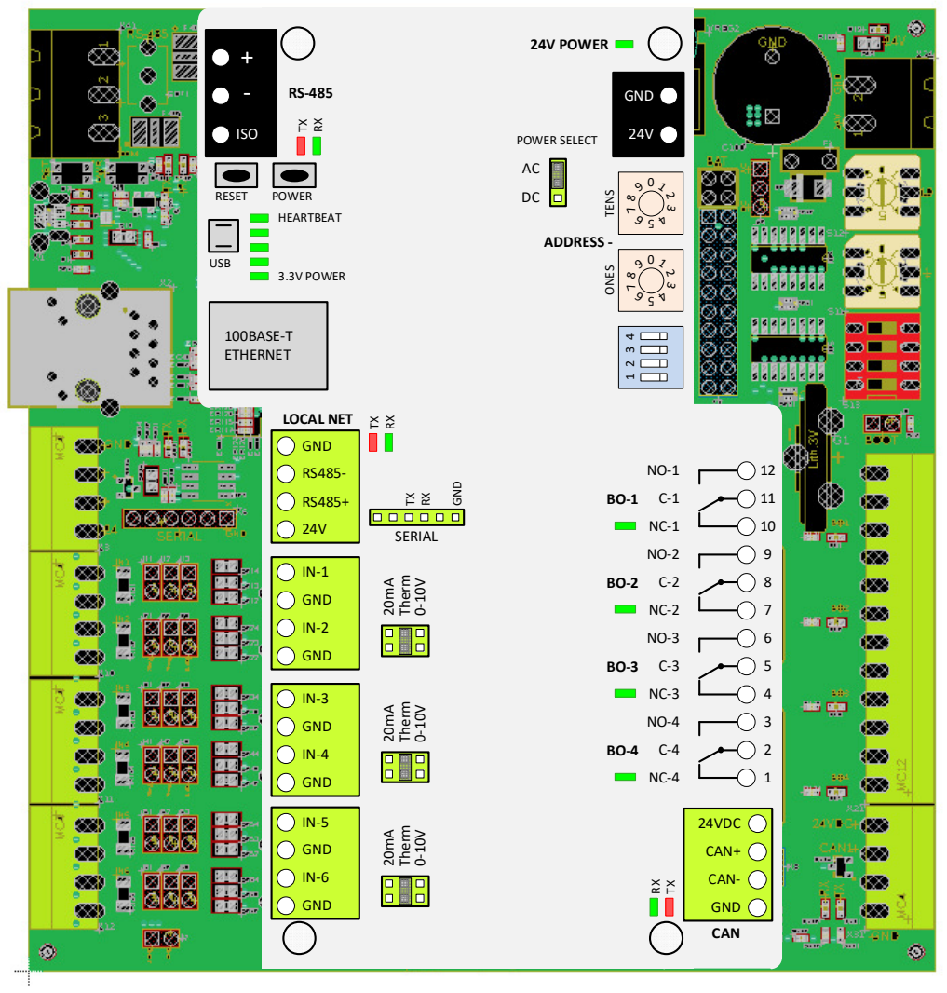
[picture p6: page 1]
24VDC; CAN+; CAN-; GND; SERIAL; ISO; LOCAL NET; CAN; TENS ONES; 24V POWER; RESET; POWER; 100BASE-T; ETHERNET; 3.3V POWER; HEARTBEAT; POWER SELECT; ADDRESS -; Therm; USB

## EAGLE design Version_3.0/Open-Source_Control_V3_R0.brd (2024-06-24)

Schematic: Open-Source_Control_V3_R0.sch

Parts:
C1, C2: DNI; C0603
C3, C6, C9, C10, C14, C15, C22, C79, C104, C301, C801, C802, C901: 0.1uF, 6.3V; C0402
C4: 47uF; C0805
C8: 1nF; C0402
C11: 220uF, 6.3V, T491C227K006AT; C/6032-28R
C21: 10uF, 10V; C0805
C85, C87, C88: 2200pF, 6.3V; C0402
C100: 1000uF, 50V, UHE1H102MHD6; PCAP_16X25-THRU-ELECT
C101, C102, C105: 0.47uF, 100V, X7R; 1206
C106: 0.1uF, 50V; 1206
C111, C121, C131, C141, C151, C161: 1uF; C0805
C401, C402, C403: 0.1uF, 16V; C0402
C404, C405: 10uF, 16V; C0805
C406: 4.7uF, 16V, T491A475K016AT; A/3216-18R
C803: 4.7uF, 6.3V; C0402
D1, D4, D5, D6, D7, D19, D31, D32, D33, D34, D302, D402, D802: LTST-C191KGKT; EIA-STD
D3: S1D; SMA
D18: B550C-13-F; SMC
D301, D401, D801: LTST-C191KRKT; EIA-STD
D305, D405: SM712; SOT23-3
D403, D404: MBR0520LT; SOD123
D805: CDSOT23-T24CAN; SOT23-3
EC30, EC31, EC34: 0.1uF, 6.3V; C0402
EC32: 10uF, 10V; C0805
EC33: 1uF, 10V; C0402
EC35: 470pF, 6.3V; C0402
EC36, EC37, EC38, EC39: 15pF, DNI; C0402
EC40: 0.022uF, 10V; C0402
EC41, EC42: 30pF, 50V; C0402
ER98, ER99, ER100, ER105: 1.5K, 1%; R0402
ER101, ER102, ER103, ER104, ER120, ER129: 10K, 1%; R0402
ER106, ER107, ER108, ER109: 49.9, 1%; R0402
ER110, ER111, ER112, ER113, ER114, ER116, ER118, ER119, ER123, ER124: 100, 1%; R0402
ER115, ER117: 470, 1%; R0402
ER122, ER126: 0, 1%; R0402
ER125: 1M, 1%, DNI; R0402
ER127: 10, 1%; R0402
ER128: 12.1K, 1%; R0402
F1: 60V, 750mA, R075; PTH
F401, F402: TBU-CA085-300-WH; TBU-CA
FB7: 150ohm, 800mA; C0805
FUD1, FUD2, FUD3, FUD4, FUD5, FUD6: FIDUCIAL; FIDUCIAL_40MIL
G1: CR2032V
GDT1: 2036-07-B3; 2036-XX-B3
IC2: ULN2003AD; SO16
IC4, IC5: 74HC165D; SO16
IC10, IC11, IC12, IC14: MCP6002SMT; SOIC8
J1, J3, J7, J11, J12, J13, J21, J22, J23, J31, J32, J33, J41, J42, J43, J45, J51, J52, J53, J61, J62, J63, J450, J454: 826646-2; H2-2.54
J24: 6p-2.54; H3-2.54
K1, K2, K3, K4: G5LE-14-CF DC24; JS-M
L2: SRP1265A-470M; SRP1265
MTG1, MTG2, MTG3, MTG4: MOUNT-PAD-ROUND3.6; 3,6-PAD
Q1: MMBT2907; SOT23-BEC
R3, R4, R25, R28, R29, R30, R33: 0, 1%; R0402
R5, R11: 0; R0402
R6, R163: 100K, DNI; R0402
R8, R301, R302, R401, R402, R801, R802: 1K; R0402
R10: 0, 1%; R0805
R12, R13, R26, R164: 1.5K, 1%; R0402
R15: 40.2K; R0402
R18, R22, R39, R40, R41: 4.75K, 1%; R0402
R20, R168, R171, R172, R173, R174: 10K; R0402
R21: 499; R0402
R27, R53, R55, R56, R57, R58, R59, R60, R61, R62, R63, R67, R68, R71, R81, R82, R83: 100K, 1%; R0402
R31: 22, 1%; R0402
R34: .1, 0805; R0805
R35: 1K; RN0804
R54, R64, R65, R66, R70, R72, R73, R74, R75, R76, R77, R78, R79, R80, R84, R85: 100K, 1%, DNI; R0402
R69: 100, 1%; R0402
R86, R87, R88, R89, R90, R91, R92, R169, R170: 10K, 1%; R0402
R181, R182, R183, R184, R185, R186: B72520T0300K062; CT/CN1206
R211, R221, R231, R241, R251, R261: 80, 0.1%; 0309/12
R212, R214, R222, R224, R232, R234, R242, R244, R252, R254, R262, R264: 10K, 1%; R0805
R213, R223, R233, R243, R253, R263: 2K, 1%; R0805
R215, R225, R235, R245, R255, R265: 100K; R0805
R281, R282, R291: 10K; RN0804
R303, R304: 1K, DNI; R0402
R305: 150, 1%; R0805
R901, R902: 1.5K, 1% DNI; R0402
RTC1: DS3231MZ+; SO08
S1, S2: KMR231GLFS; SW4SMD_63X161LS
S11, S12: P101
S13: DS04; DS-04
T4: DA2304-AL; DA230X-AL
TP1, TP2, TP3, TP4, TP11, TP12, TP13, TP14, TP15, TP16, TP21, TP22, TP23, TP24, TP26, TP31, TP32, TP33: TPB0,65; TP_B0,65
TP5, TP6, TP7, TP8, TP9, TP10, TP17, TP18, TP19, TP20: TESTPAD/W_HOLE_1X1
U1: OSD3358-512M-ICB; OSD335X-BGA-400
U2: TPD4S012_DRY_6_P1_M; DRY6
U4: APX811-31UGSOT; SOT143-R
U5: TLVH431; SOT23-3
U6: SN74LVC2G241_DCU_8; DCU8
U16: AT97SC3205T-G3M4400B; QFN32-0.4-4X4MM
U27: LAN8710; LAN8710A-QFN32
U28: TCAN1051HV; BEAGLEBONE_BLUE_D8
U29: MAX3483EESA+T; 21-0041B_8
U40: ISO3086TDW; DW16
VREG1: LM2596S-5.0; TO263-5
VREG2: L7824CV; 78XXL
VREG4: TPS76350; DBV5
X1: 10118194-0001LF; 10118194-0001LF(MICRO-USB-B-AMPHENOL-FCI)
X2: J0011D01BNL
X3, X10, X11, X12, X31: MC4
X4: CTI-JTAG
X5: DM3CS-SF
X6: 6p-2.54; H6-2.54
X7, X8: TH-2X10; H2X10-2.54
X9: 5600200420
X21: MC12
X24: MSTBA2
X41: MSTBA3
Y7: ECS-250-12-30-GN-TR; XTAL_2-SMD(5X3.2MM)

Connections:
1P8V_REF_1: IC10.8 (V+), IC11.8 (V+), IC14.1 (OUT), IC14.2 (-IN), R212.2, R222.2, R232.2, R242.2
1P8V_REF_2: IC12.8 (V+), IC14.6 (-IN), IC14.7 (OUT), R252.2, R262.2
5V_OUT: D18.C, L2.1, VREG1.2 (OUT)
24LIN_IN: C105.1, J24.1, VREG2.IN
24VAC: D3.A, F1.P$2 (2)
24VAC_IN: F1.P$1 (1), X3.4, X24.1
24VDC_AUX: C106.1, D19.1 (A), D31.1 (A), D32.1 (A), D33.1 (A), D34.1 (A), IC2.9 (CD+), J24.3, K1.1, K2.1, K3.1, K4.1, VREG2.OUT, X8.11, X8.19, X31.4
24VDC_UNREG: C100.1, C101.1, D3.C, J24.2, VREG1.1 (IN)
41_A: F402.1, GDT1.1, X41.2
41_B: F401.1, GDT1.2, X41.1
485_A: D305.1, R304.2, R305.2, U29.6 (A), X3.2
485_B: D305.2, R303.1, R305.1, U29.7 (B), X3.3
485_RXD: D402.2 (C), J45.1, U40.5 (R)
485_TXD: D401.2 (C), J45.2, U40.8 (D)
AGND: C8.2, C9.2, C10.2, C111.2, C121.2, C131.2, C141.2, C151.2, C161.2, IC10.4 (V-), IC11.4 (V-), IC12.4 (V-), J7.1, R25.2, R181.2, R182.2, R183.2, R184.2, R185.2, R186.2, R211.1, R213.2, R215.2, R221.1, R223.2, R225.2, R231.1, R233.2, R235.2, R241.1, R243.2, R245.2, R251.1, R253.2, R255.2, R261.1, R263.2, R265.2, U1.Y9 (AGND_ADC), X10.2, X10.4, X11.2, X11.4, X12.2, X12.4
AIN0: U1.Y10 (AIN0)
AIN1: IC10.1 (OUT), IC10.2 (-IN), R215.1, U1.W10 (AIN1)
AIN2: IC10.6 (-IN), IC10.7 (OUT), R225.1, U1.V10 (AIN2)
AIN3: IC11.1 (OUT), IC11.2 (-IN), R235.1, U1.V9 (AIN3)
AIN4: IC11.6 (-IN), IC11.7 (OUT), R245.1, U1.Y11 (AIN4)
AIN5: IC12.1 (OUT), IC12.2 (-IN), R255.1, U1.W11 (AIN5)
AIN6: IC12.6 (-IN), IC12.7 (OUT), R265.1, U1.V11 (AIN6)
AIN7: U1.U12 (PMIC_MUX_OUT), U1.V12 (AIN7)
B03_NO: K3.NO (S), X21.6
BAT_SENSE: TP6.P$1, U1.E19 (PMIC_BAT_SENSE)
BO1: K1.2, R171.2, X8.10
BO1_AUTO: IC2.16 (O1), X8.9
BO1_C: K1.C, X21.11
BO1_NC: K1.NC (O), X21.10
BO1_NO: K1.NO (S), X21.12
BO2: K2.2, R172.2, X8.8
BO2_AUTO: IC2.15 (O2), X8.7
BO2_C: K2.C, X21.8
BO2_NC: K2.NC (O), X21.7
BO2_NO: K2.NO (S), X21.9
BO3: K3.2, R173.2, X8.6
BO3_AUTO: IC2.14 (O3), X8.5
BO3_C: K3.C, X21.5
BO3_NC: K3.NC (O), X21.4
BO4: K4.2, R174.2, X8.4
BO4_AUTO: IC2.13 (O4), X8.3
BO4_C: K4.C, X21.2
BO4_NC: K4.NC (O), X21.1
BO4_NO: K4.NO (S), X21.3
BO5_AUTO: IC2.12 (O5), X8.1
BO6_AUTO: IC2.11 (O6), X8.12
B_UART0_RX: R27.2, U6.2 (1A), X6.4
B_UART0_TX: U6.3 (2Y), X6.5
CAN1_RXD: D802.2 (C), U1.W7 (UART1_TXD), U28.4 (RXD)
CAN1_TXD: D801.2 (C), U1.Y7 (UART1_RXD), U28.1 (TXD)
CAN_H: D805.2, U28.7 (CANH), X31.3
CAN_L: D805.1, U28.6 (CANL), X31.2
CGND: MTG1.B3,6, MTG2.B3,6, MTG3.B3,6, MTG4.B3,6, R34.2, X1.CGND1 (SGND1), X1.CGND2 (SGND2), X1.CGND3 (SGND3), X1.CGND4 (SGND4), X1.CGND5 (SGND5), X1.CGND6 (SGND6), X2.S1 (SHD1), X2.S2 (SHD2), X5.9 (GND_1), X5.10 (GND_2), X5.11 (GND_3), X5.13 (GND_4)
CLKOUT2: C2.2, R3.2, X4.18 (EMU3)
CRS: ER124.1, U27.14 (CRS)
EEPROM_WP: J1.1, U1.M2 (EEPROM_WP)
EHRPWM1A: U1.C13 (GPMC_A2), X8.15
EHRPWM1B: U1.A12 (GPMC_A3)
EHRPWM2A: U1.A17 (GPMC_AD8), X8.13
EHRPWM2B: U1.C16 (GPMC_AD9), X8.14
E_LED_GRN: U27.3 (LED1/REGOFF), X2.9 (GRNA)
E_LED_YEL: ER120.2, U27.2 (LED2/!INTSEL), X2.12 (YELA)
GND: C1.1, C2.1, C3.2, C4.2, C6.1, C11.-, C14.2, C15.2, C21.2, C22.2, C79.2, C85.2, C87.2, C88.2, C100.2, C101.2, C102.2, C104.2, C105.2, C106.2, C301.2, C401.2, C404.2, C801.2, C802.2, C803.2, C901.2, D18.A, D305.3, D805.3, EC30.2, EC31.2, EC32.2, EC33.2, EC34.2, EC35.2, EC36.2, EC37.2, EC38.2, EC39.2, EC40.2, EC41.2, EC42.2, ER101.2, ER102.2, ER103.2, ER104.2, ER115.1, ER117.1, ER120.1, ER128.1, ER129.2, G1.-, IC2.8 (GND), IC4.8 (GND), IC4.15 (INH), IC5.3 (E), IC5.4 (F), IC5.5 (G), IC5.6 (H), IC5.8 (GND), IC5.10 (SER), IC5.15 (INH), IC14.4 (V-), J1.2, J3.2, J7.2, R6.1, R18.1, R26.2, R27.1, R34.1, R35.1, R35.2, R35.3, R35.4, R39.1, R53.1, R54.1, R55.1, R56.1, R57.1, R58.1, R59.1, R60.1, R61.1, R62.1, R63.1, R64.1, R65.1, R66.1, R67.1, R68.1, R168.2, R281.1, R281.2, R281.3, R281.4, R282.1, R282.2, R282.3, R282.4, R291.1, R291.2, R291.3, R291.4, R304.1, RTC1.5 (GND), S1.2, S1.4, S2.1, S2.3, TP8.P$1, U1.A1 (DGND), U1.A20 (DGND), U1.D4 (DGND), U1.D5 (DGND), U1.D15 (DGND), U1.D16 (DGND), U1.D17 (DGND), U1.E4 (DGND), U1.E5 (DGND), U1.E6 (DGND), U1.E7 (DGND), U1.E8 (DGND), U1.E9 (DGND), U1.E10 (DGND), U1.E11 (DGND), U1.E12 (DGND), U1.E13 (DGND), U1.E14 (DGND), U1.E15 (DGND), U1.E16 (DGND), U1.E17 (DGND), U1.F5 (DGND), U1.F10 (DGND), U1.F11 (DGND), U1.F16 (DGND), U1.F17 (DGND), U1.G5 (DGND), U1.G16 (DGND), U1.H5 (DGND), U1.H16 (DGND), U1.J5 (DGND), U1.J9 (DGND), U1.J10 (DGND), U1.J11 (DGND), U1.J12 (DGND), U1.J13 (DGND), U1.J16 (DGND), U1.K5 (DGND), U1.K6 (DGND), U1.K7 (DGND), U1.K8 (DGND), U1.K9 (DGND), U1.K12 (DGND), U1.K15 (DGND), U1.K16 (DGND), U1.L5 (DGND), U1.L6 (DGND), U1.L15 (DGND), U1.L16 (DGND), U1.M5 (DGND), U1.M15 (DGND), U1.M16 (DGND), U1.N5 (DGND), U1.N6 (DGND), U1.N15 (DGND), U1.N16 (DGND), U1.P5 (DGND), U1.P6 (DGND), U1.P7 (DGND), U1.P8 (DGND), U1.P9 (DGND), U1.P12 (DGND), U1.P13 (DGND), U1.P14 (DGND), U1.P15 (DGND), U1.P16 (DGND), U1.R5 (DGND), U1.R9 (DGND), U1.R10 (DGND), U1.R11 (DGND), U1.R12 (DGND), U1.R16 (DGND), U1.T4 (DGND), U1.T5 (DGND), U1.T6 (DGND), U1.T7 (DGND), U1.T8 (DGND), U1.T9 (DGND), U1.T10 (DGND), U1.T11 (DGND), U1.T12 (DGND), U1.T13 (DGND), U1.T14 (DGND), U1.T15 (DGND), U1.T16 (DGND), U1.T17 (DGND), U1.U4 (DGND), U1.U5 (DGND), U1.U15 (RTC_KALDO_ENN), U1.U16 (DGND), U1.U17 (DGND), U1.W13 (OSC1_GND), U1.Y1 (DGND), U1.Y20 (DGND), U2.4 (GND), U4.1 (GND), U6.1 (*1OE), U6.4 (GND), U16.2 (GND), U16.5 (TESTL), U16.6 (XTAMPER), U16.9 (GND), U16.18 (PIRQ#), U16.19 (ATEST), U16.20 (TWI_WAKEUP#), U16.21 (ATEST), U16.23 (GND), U16.24 (ATEST), U16.32 (GND), U27.33 (GND_EP), U28.2 (GND), U29.5 (GND), U40.3 (GND1), VREG1.3 (GND), VREG1.5 (EN), VREG1.6 (GND), VREG2.GND, X1.GND, X2.8 (D_GND), X3.1, X4.4 (TDIS), X4.8 (GND1), X4.10 (GND2), X4.12 (GND3), X4.16 (GND4), X4.20 (GND5), X5.6 (VSS), X6.1, X8.2, X8.16, X9.P$2 (2), X24.2, X31.1
GPIO0_7: U1.V15 (ECAP0_IN_PWM0_OUT), U29.2 (!RE), U29.3 (DE)
GPIO0_18: U1.K3 (USB0_DRVVBUS)
GPIO1_12: IC2.2 (I2), U1.C15 (GPMC_AD12)
GPIO1_13: IC2.3 (I3), U1.B15 (GPMC_AD13)
GPIO1_14: IC2.4 (I4), U1.A15 (GPMC_AD14)
GPIO1_15: IC2.5 (I5), U1.C14 (GPMC_AD15)
GPIO1_16: IC2.6 (I6), U1.A13 (GPMC_A0)
GPIO1_17: IC2.1 (I1), U1.B13 (GPMC_A1)
GPIO1_28: U1.C9 (GPMC_BEN1)
I2C0_SCL: R12.1, TP18.P$1, U1.U8 (PMIC_SCL), U1.V8 (I2C0_SCL), U16.29 (SM_CLK)
I2C0_SDA: R13.1, TP17.P$1, U1.U7 (PMIC_SDA), U1.V7 (I2C0_SDA), U16.30 (SM_DAT)
I2C2_SCL: R169.1, R901.1, RTC1.8 (SCL), TP20.P$1, U1.Y8 (UART1_RTSN), X9.P$4 (4)
I2C2_SDA: R170.1, R902.1, RTC1.7 (SDA), TP19.P$1, U1.W8 (UART1_CTSN), X9.P$1 (1)
ISO_485_A: D405.2, F402.3, U40.11 (Y), U40.14 (A)
ISO_485_B: D405.1, F401.3, U40.12 (Z), U40.13 (B)
ISO_GND: C402.2, C403.2, C405.2, C406.-, D405.3, GDT1.3, T4.P$6 (6), T4.P$7 (7), U40.9 (GND2_2), U40.15 (GND2), VREG4.2 (GND), X41.3
ISO_VCC: C402.1, C406.+, U40.16 (VCC2), VREG4.5 (VOUT)
ISO_VIN: C403.1, C405.1, D403.C, D404.C, VREG4.1 (VIN), VREG4.3 (ON/!OFF)
JTAG_EMU0: R40.1, U1.V18 (EMU0), X4.13 (EMU0)
JTAG_EMU1: R41.1, U1.V19 (EMU1), X4.14 (EMU1)
JTAG_TCK: U1.Y19 (TCK), X4.9 (TCKRTN), X4.11 (TCK)
JTAG_TDI: U1.Y18 (TDI), X4.3 (TDI)
JTAG_TDO: U1.W18 (TDO), X4.7 (TDO)
JTAG_TMS: U1.W19 (TMS), X4.1 (TMS)
JTAG_TRSTN: R39.2, U1.W20 (TRSTN), X4.2 (TRSTN)
LCD_DATA0: R68.2, R85.1, U1.T18 (LCD_DATA0), X7.19
LCD_DATA1: R67.2, R84.1, U1.T19 (LCD_DATA1), X7.20
LCD_DATA2: R66.2, R69.1, R83.1, U1.T20 (LCD_DATA2), X7.17
LCD_DATA3: R65.2, R82.1, U1.R18 (LCD_DATA3), X7.18
LCD_DATA4: R64.2, R81.1, U1.R19 (LCD_DATA4), X7.15
LCD_DATA5: R63.2, R80.1, U1.R20 (LCD_DATA5), X7.16
LCD_DATA6: R62.2, R79.1, U1.P18 (LCD_DATA6), X7.13
LCD_DATA7: R61.2, R78.1, U1.P19 (LCD_DATA7), X7.14
LCD_DATA8: R60.2, R77.1, U1.P20 (LCD_DATA8), X7.11
LCD_DATA9: R59.2, R76.1, U1.N18 (LCD_DATA9), X7.12
LCD_DATA10: R58.2, R75.1, U1.N19 (LCD_DATA10), X7.10
LCD_DATA11: R57.2, R74.1, U1.N20 (LCD_DATA11), X7.8
LCD_DATA12: R56.2, R73.1, U1.M18 (LCD_DATA12), X7.9
LCD_DATA13: R55.2, R72.1, U1.M19 (LCD_DATA13), X7.7
LCD_DATA14: R54.2, R71.1, U1.M20 (LCD_DATA14), X7.5
LCD_DATA15: R53.2, R70.1, U1.L18 (LCD_DATA15), X7.6
LCD_DE: R28.2, X7.4
LCD_HSYNC: R29.2, X7.3
LCD_PCLK: R31.2, X7.2
LCD_VSYNC: R30.2, X7.1
LDO_PGOOD: TP22.TP, U1.D13 (RTC_PWRONRSTN), U1.D14 (PMIC_LDO_PGOOD)
MDIO_CLK: U1.W1 (MDC), U27.17 (MDC)
MDIO_DATA: ER105.2, U1.V1 (MDIO), U27.16 (MDIO)
MII1_COL: ER123.2, U1.R2 (MII1_COL)
MII1_CRS: ER124.2, U1.R3 (MII1_CRS)
MII1_RXCLK: ER116.2, U1.T1 (MII1_RX_CLK)
MII1_RXD0: ER113.2, U1.T3 (MII1_RXD0)
MII1_RXD1: ER112.2, U1.U1 (MII1_RXD1)
MII1_RXD2: ER111.2, U1.U2 (MII1_RXD2)
MII1_RXD3: ER110.2, U1.U3 (MII1_RXD3)
MII1_RXDV: ER114.2, U1.R1 (MII1_RX_DV)
MII1_RXERR: ER118.2, U1.T2 (MII1_RX_ER)
MII1_TXCLK: ER119.2, U1.N1 (MII1_TX_CLK)
MII1_TXD0: U1.N2 (MII1_TXD0), U27.22 (TXD0)
MII1_TXD1: U1.N3 (MII1_TXD1), U27.23 (TXD1)
MII1_TXD2: U1.P1 (MII1_TXD2), U27.24 (TXD2)
MII1_TXD3: U1.P2 (MII1_TXD3), U27.25 (TXD3)
MII1_TXEN: U1.P3 (MII1_TX_EN), U27.21 (TXEN)
MMC0_CD: R92.1, U1.V4 (SPI0_CS1), X4.19 (EMU4), X5.12 (CARD_DETECTION_SWITCH)
MMC0_CLK: R88.1, U1.W3 (MMC0_CLK), X5.5 (CLK)
MMC0_CMD: R87.1, U1.W2 (MMC0_CMD), X5.3 (CMD)
MMC0_DAT0: R89.1, U1.Y3 (MMC0_DAT0), X5.7 (DAT0)
MMC0_DAT1: R90.1, U1.V3 (MMC0_DAT1), X5.8 (DAT1)
MMC0_DAT2: R86.1, U1.V2 (MMC0_DAT2), X5.1 (DAT2)
MMC0_DAT3: R91.1, U1.Y2 (MMC0_DAT3), X5.2 (CD/DAT3)
MODE2: ER99.2, ER123.1, U27.15 (COL/CRS_DV/MODE2)
unnamed: R10.1, X1.VBUS
unnamed: D7.2 (C), R35.8
unnamed: D31.2 (C), R171.1
unnamed: D802.1 (A), R802.2
unnamed: D801.1 (A), R801.2
unnamed: J51.1, J52.1, R185.1, R254.1, X12.1
unnamed: D1.2 (C), R26.1
unnamed: TP33.TP, U1.F18 (SYS_VDD1_CTL)
unnamed: ER117.2, X2.10 (GRNC)
unnamed: D6.2 (C), R35.7
unnamed: D5.2 (C), R35.6
unnamed: J11.1, J12.1, R181.1, R214.1, X10.1
unnamed: D4.2 (C), R35.5
unnamed: D402.1 (A), R402.2
unnamed: D401.1 (A), R401.2
unnamed: D301.1 (A), R301.2
unnamed: D302.1 (A), R302.2
unnamed: C151.1, IC12.3 (+IN), J53.1, R254.2
unnamed: J51.2, R251.2
unnamed: J53.2, R253.1
unnamed: J52.2, R252.1
unnamed: J61.1, J62.1, R186.1, R264.1, X12.3
unnamed: C161.1, IC12.5 (+IN), J63.1, R264.2
unnamed: J61.2, R261.2
unnamed: J11.2, R211.2
unnamed: J12.2, R212.1
unnamed: J63.2, R263.1
unnamed: J62.2, R262.1
unnamed: J13.2, R213.1
unnamed: J21.1, J22.1, R182.1, R224.1, X10.3
unnamed: C121.1, IC10.5 (+IN), J23.1, R224.2
unnamed: C111.1, IC10.3 (+IN), J13.1, R214.2
unnamed: J21.2, R221.2
unnamed: J23.2, R223.1
unnamed: J22.2, R222.1
unnamed: J31.1, J32.1, R183.1, R234.1, X11.1
unnamed: C131.1, IC11.3 (+IN), J33.1, R234.2
unnamed: J31.2, R231.2
unnamed: J33.2, R233.1
unnamed: R31.1, U1.U20 (LCD_PCLK)
unnamed: J32.2, R232.1
unnamed: R30.1, U1.U18 (LCD_VSYNC)
unnamed: J41.1, J42.1, R184.1, R244.1, X11.3
unnamed: C141.1, IC11.5 (+IN), J43.1, R244.2
unnamed: J41.2, R241.2
unnamed: J43.2, R243.1
unnamed: J42.2, R242.1
unnamed: R29.1, U1.U19 (LCD_HSYNC)
unnamed: R28.1, U1.V20 (LCD_AC_BIAS_EN)
unnamed: D403.A, T4.P$8 (8)
unnamed: D404.A, T4.P$5 (5)
unnamed: T4.P$1 (1), U40.1 (D1)
unnamed: T4.P$4 (4), U40.2 (D2)
unnamed: D19.2 (C), R168.1
unnamed: EC40.1, ER122.2, X2.4 (TCT), X2.5 (RCT)
unnamed: IC4.6 (H), R282.5, S12.8
unnamed: IC4.5 (G), R282.6, S12.4
unnamed: IC4.4 (F), R282.7, S12.2
unnamed: IC4.3 (E), R282.8, S12.1
unnamed: IC4.14 (D), R281.5, S11.8
unnamed: IC4.13 (C), R281.6, S11.4
unnamed: IC4.12 (B), R281.7, S11.2
unnamed: IC4.11 (A), R281.8, S11.1
unnamed: IC4.10 (SER), IC5.9 (QH)
unnamed: IC5.11 (A), R291.8, S13.8
unnamed: IC5.12 (B), R291.7, S13.7
unnamed: IC5.13 (C), R291.6, S13.6
unnamed: IC5.14 (D), R291.5, S13.5
unnamed: G1.+, RTC1.6 (VBAT)
unnamed: J3.1, R69.2
unnamed: D32.2 (C), R172.1
unnamed: ER126.1, U27.5 (XTAL1/CLKIN)
unnamed: EC42.1, ER125.2, ER126.2, Y7.P$2 (2)
unnamed: EC41.1, ER127.2, Y7.P$1 (1)
unnamed: ER125.1, ER127.1, U27.4 (XTAL2)
unnamed: ER128.2, U27.32 (RBIAS)
unnamed: ER129.1, U27.18 (NINT/TXER/TXD4)
unnamed: D33.2 (C), R173.1
unnamed: D34.2 (C), R174.1
unnamed: EC33.1, EC35.1, U27.6 (VDDCR)
unnamed: ER115.2, X2.11 (YELC)
unnamed: R15.2, R20.1, U5.1 (REF)
unnamed: Q1.B, R21.1, U5.2 (CATHODE)
unnamed: R4.1, U1.W14 (XDMA_EVENT_INTR0)
unnamed: R11.1, S1.1, S1.3
unnamed: R8.2, U4.2 (RESET#)
unnamed: R5.2, R11.2, U4.3 (MR#)
unnamed: R3.1, U1.V14 (XDMA_EVENT_INTR1)
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

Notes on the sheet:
Power & Reset
Clocks, Analog & USB
SiP Interfaces
Boot configuration
10/100BASE-T Ethernet
LCD Header
Micro SD card slot
User LEDs
JTAG Header
USB Client
SiP GND & Misc
1/15
3/15
2/15
4/15
5/15
6/15
9/15
8/15
7/15
Mounting Holes
Fiducials
TPM
Local Network RS-485
Notes
12/15
11/15
10/15
13/15
14/15
Universal Inputs
Isolated RS-485 Interface
Power Supply
CAN Interface
User Config Switches
External Real Time Clk
Relay Outputs
Modular IO Connections
15/15

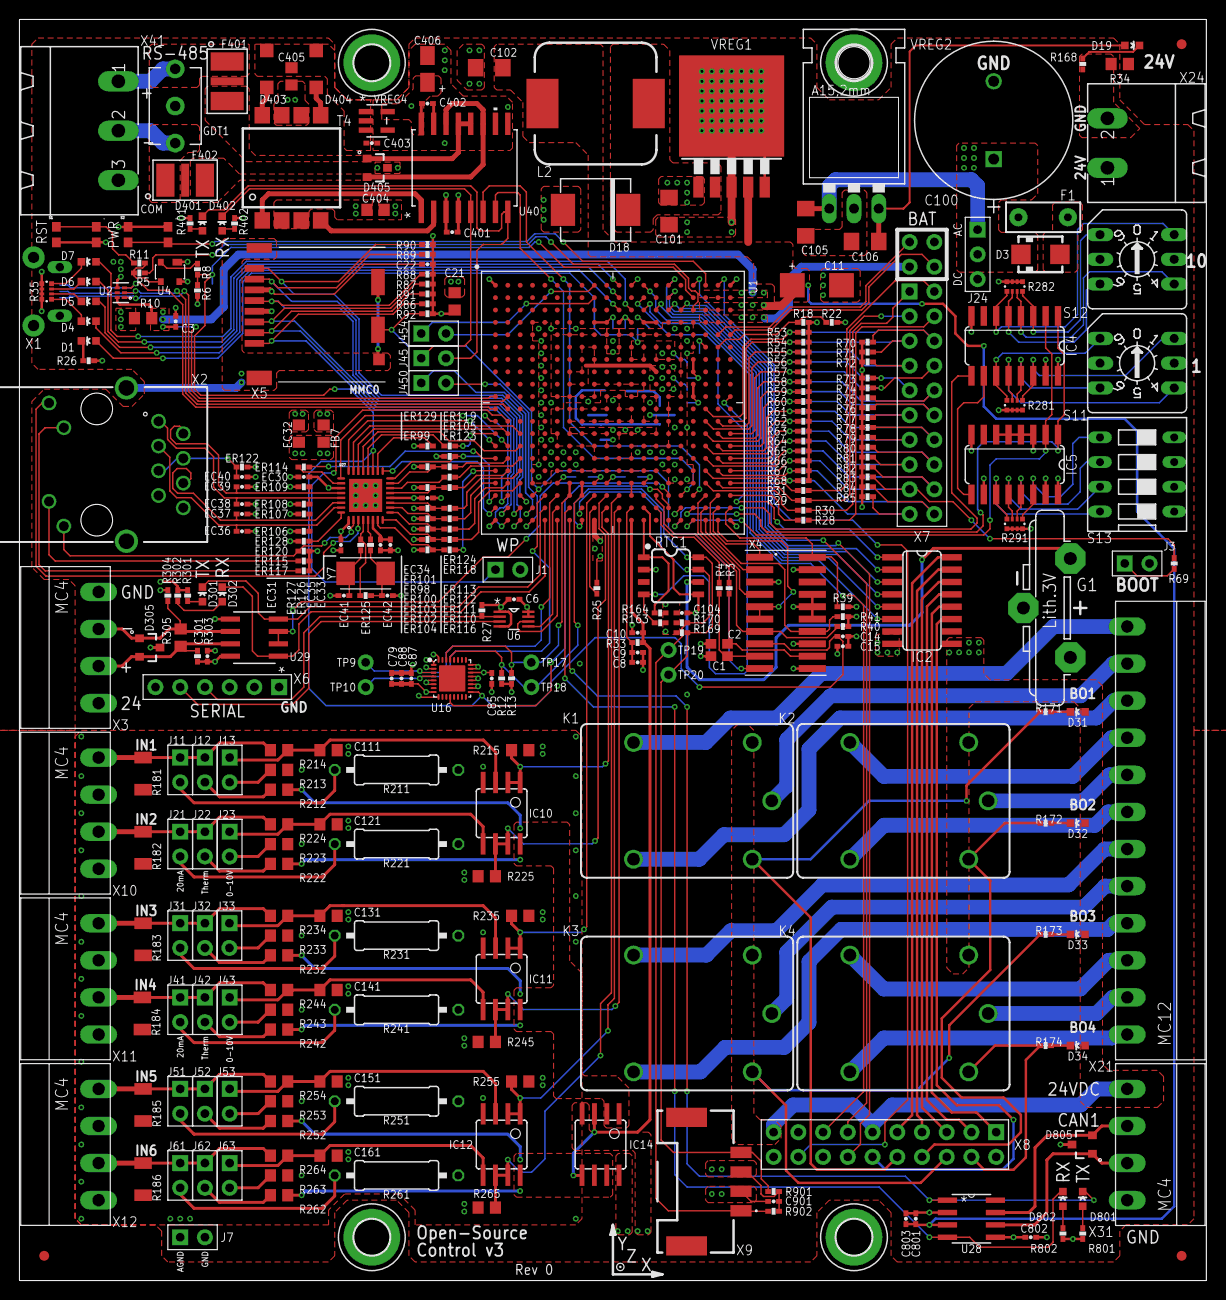
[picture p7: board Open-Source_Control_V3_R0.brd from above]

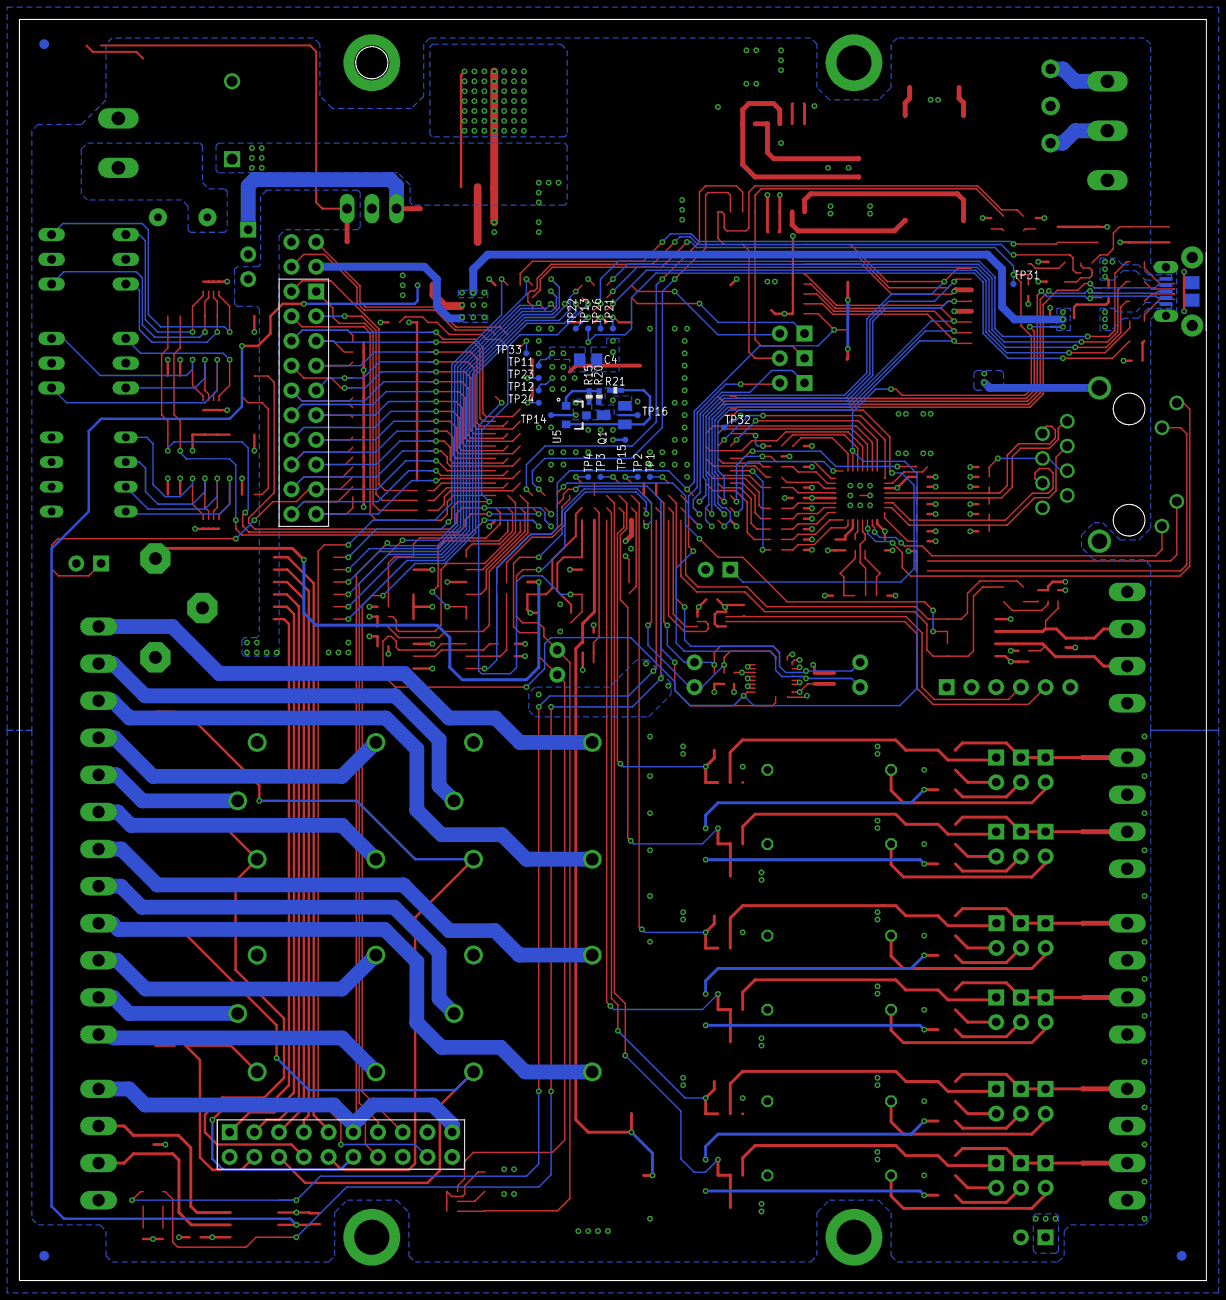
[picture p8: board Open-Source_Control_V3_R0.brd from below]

Board: 4 copper layers, 121.9 x 129.5 mm, 353 parts (28 on the bottom side), 284 nets.

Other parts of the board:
U$2: XYZ-LABEL

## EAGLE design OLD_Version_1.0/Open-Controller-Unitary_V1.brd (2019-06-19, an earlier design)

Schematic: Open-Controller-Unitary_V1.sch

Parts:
C1, C2: DNI; C0603
C3, C6, C9, C10, C14, C15, C17, C18, C19, C20, C22, C79, C93, C97: 0.1uF, 6.3V; C0402
C4: 330pF, DNI; C0805
C7, C12: 18pF, 50V; C0402
C8: 1nF; C0402
C11: 220uF, 6.3V; B/3528-21R
C13: 2.2uF, 6.3V; C0402
C16, C21: 10uF, 10V; C0805
C41, C44: 10uF, 16V; C0805
C42, C43, C45: 0.1uF, 16V; C0402
C46, C95, C96: 4.7uF; 1206
C85, C87, C88: 2200pF, 6.3V; C0402
C94: 1mF; CPOL-RADIAL-5MM-10MM
C111, C121, C131, C141, C151, C161: 1uF; C0805
D1, D2, D9, D21, D22, D23, D24, D25: LTST-C191KFKT; EIA-STD
D3: S1D; SMA
D4, D5, D6, D7, D8: LTST-C191KGKT; EIA-STD
D10, D11: SMBJ7.0CA; SMBJ
D13: B550C-13-F; SMC
D14, D15: SMBJ12CA; SMBJ
D16, D17: MBR0520LT; SOD123
EC30, EC31, EC34: 0.1uF, 6.3V; C0402
EC32: 10uF, 10V; C0805
EC33: 1uF, 10V; C0402
EC35: 470pF, 6.3V; C0402
EC36, EC37, EC38, EC39: 15pF, DNI; C0402
EC40: 0.022uF, 10V; C0402
EC41, EC42: 30pF, 50V; C0402
ER98, ER99, ER100, ER105: 1.5K, 1%; R0402
ER101, ER102, ER103, ER104, ER120, ER129: 10K, 1%; R0402
ER106, ER107, ER108, ER109: 49.9, 1%; R0402
ER110, ER111, ER112, ER113, ER114, ER116, ER118, ER119, ER123, ER124: 100, 1%; R0402
ER115, ER117: 470, 1%; R0402
ER122, ER126: 0, 1%; R0402
ER125: 1M, 1%, DNI; R0402
ER127: 10, 1%; R0402
ER128: 12.1K, 1%; R0402
F1: 4A Fuse; F1206W
F3, F4: MICROSMD010F-2; FUS_MICROSMD010F_TYCO
FB7: 150ohm, 800mA; C0805
FUD1, FUD2, FUD3, FUD4, FUD5, FUD6: FIDUCIAL; FIDUCIAL_40MIL
G1: CR2032V
IC1: LM2596S; TO263-5
IC2: ULN2003AD; SO16
IC3: L7824CT; 78XXL
IC4, IC5: 74HC165D; SO16
J1, J2, J6, J11, J12, J13, J21, J22, J23, J31, J32, J33, J41, J42, J43, J51, J52, J53, J61, J62, J63: 826646-2; H2-2.54
J3: 6p-2.54; H6-2.54
J4: CTI-JTAG
J7, J8: TH-2X5; H2X5-2.54
K1, K2, K3, K4, K5: JS1-24V-F; JS-M
L2: MSS1260
L3: 78253/55MVC-R; IND_78253_MC
MGT1, MGT2, MGT3, MGT4: MOUNTING_HOLE
Q1: MMBT2907; SOT23-BEC
R1, R3, R20, R42, R43, R44, R45, R46, R47, R48, R49, R50, R51, R52, R86, R87, R88, R89, R90, R91, R92, R160, R161, R171, R172, R173, R174, R175, R281, R282, R283, R284, R285, R286, R287, R288, R291, R292, R293, R294: 10K, 1%; R0402
R2, R9, R12, R13, R24, R26, R35, R36, R37, R38, R95, R96: 1.5K, 1%; R0402
R4, R5, R11, R19, R25, R28, R29, R30, R33: 0, 1%; R0402
R6, R54, R64, R65, R66, R70, R72, R73, R74, R75, R76, R77, R78, R79, R80, R84, R85: 100K, 1%, DNI; R0402
R8: 1K, 1%; R0402
R10: 0, 1%; R0805
R15: 40.2K, 1%; R0402
R17: 1.00K, 1%; R0805
R18, R22, R39, R40, R41: 4.75K, 1%; R0402
R21: 499; R0402
R27, R53, R55, R56, R57, R58, R59, R60, R61, R62, R63, R67, R68, R71, R81, R82, R83, R158: 100K, 1%; R0402
R31: 22, 1%; R0402
R32: 1M, 1%; R0402
R34: .1, 0805; R0805
R69: 100, 1%; R0402
R93: 3.09K, 1%; R0805
R94: 100, 5% DNI; R0805
R181, R182, R183, R184, R185, R186: 47V 200A; CT/CN1206
R211, R221, R231, R241, R251, R261: 80, 0.1%; 0309/12
R212, R214, R222, R224, R232, R234, R242, R244, R252, R254, R262, R264: 10K, 1%; R0805
R213, R223, R233, R243, R253, R263: 2K, 1%; R0805
RTC1: DS3231M; SO08
S1, S2: KMR231GLFS; SW4SMD_63X161LS
S11, S12: P101
S13: DS04; DS-04
TP1, TP2, TP3, TP4, TP12, TP13, TP14, TP15, TP16, TP21, TP22, TP23, TP24, TP27, TP28, TP29, TP30: TPB0,65; TP_B0,65
TP5, TP6, TP7, TP8, TP9, TP10, TP26: TESTPAD/W_HOLE_1X1
U1: OSD3358-512M-BSM; OSD335X-BGA-256
U2: TPD4S012_DRY_6_P1_M; DRY6
U3: SN74LVC1G07_DCK_5; DCK5
U4: APX811SOT; SOT143-R
U5: TLVH431; SOT23-3
U6: SN74LVC2G241_DCU_8; DCU8
U7: EMMC04G-S100-B08U; MICRON_EMMC_153
U8: LAN8710; LAN8710A-QFN32
U16: AT97SC3205T-G3M4400B; QFN32-0.4-4X4MM
U21: S25FL127S; W-PDFN-8
U25: ISO3086TDW; DW16
U26: LP2985A-33DBVR; DBV5
U27: TCAN1051HV; BEAGLEBONE_BLUE_D8
U$3, U$5, U$6: MCP6002SMT; SOIC8
U$4: MCP6001; SOT23-5
X1: 10118192-0001LF; 10118192-0001LF(MICRO-USB-B-AMPHENOL-FCI)
X2: MC2
X3: DM3BT-DSF-PEJS
X4: J0011D01BNL; SI-50170
X7: MSTBA2
X8: MC10
X9, X10, X11: MC4
X12: MC3
X13: MSTBA3
Y2: 7A-24.000MAAJ-T; CRYSTAL-TXC-7A
Y7: 7A-25.000MAAE-T; CRYSTAL-TXC-7A

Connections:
1P8V_REF: R212.2, R222.2, R232.2, R242.2, R252.2, R262.2, U$3.8 (V+), U$4.1 (OUT), U$4.4 (-IN), U$5.8 (V+), U$6.8 (V+)
5V_OUT: D13.C, IC1.2 (OUT), L2.1
24VAC: D3.A, F1.2
24VAC_IN: F1.1, X7.1
24VAC_UNREG: C94.+, C95.1, D3.C, IC1.1 (IN), IC3.IN
24VDC_AUX: D2.1 (A), D21.1 (A), D22.1 (A), D23.1 (A), D24.1 (A), D25.1 (A), IC2.9 (CD+), IC3.OUT, K1.1, K2.1, K3.1, K4.1, K5.1, X2.1, X2.2
AGND: C8.2, C9.2, C10.2, C111.2, C121.2, C131.2, C141.2, C151.2, C161.2, R25.2, R211.1, R213.2, R221.1, R223.2, R231.1, R233.2, R241.1, R243.2, R251.1, R253.2, R261.1, R263.2, U1.A9 (AGND_ADC), U$3.4 (V-), U$4.2 (V-), U$5.4 (V-), U$6.4 (V-), X9.2, X9.4, X10.2, X10.4, X11.2, X11.4
AIN0: U1.A8 (AIN0)
AIN1: U1.B8 (AIN1), U$3.1 (OUT), U$3.2 (-IN)
AIN2: U1.B6 (AIN2), U$3.6 (-IN), U$3.7 (OUT)
AIN3: U1.C6 (AIN3), U$5.1 (OUT), U$5.2 (-IN)
AIN4: U1.C7 (AIN4), U$5.6 (-IN), U$5.7 (OUT)
AIN5: U1.C8 (AIN5), U$6.1 (OUT), U$6.2 (-IN)
AIN6: U1.C9 (AIN6), U$6.6 (-IN), U$6.7 (OUT)
AIN7: U1.D6 (PMIC_MUX_OUT), U1.D7 (AIN7)
B03_NO: K3.NO (S), X8.6
BAT_SENSE: TP6.P$1, U1.N7 (PMIC_BAT_SENSE)
BO1_C: K1.C, X8.9
BO1_NO: K1.NO (S), X8.10
BO2_C: K2.C, X8.7
BO2_NO: K2.NO (S), X8.8
BO3_C: K3.C, X8.5
BO4_C: K4.C, X8.3
BO4_NO: K4.NO (S), X8.4
BO5_C: K5.C, X8.1
BO5_NO: K5.NO (S), X8.2
B_UART0_RX: J3.4, R27.2, U6.2 (1A)
B_UART0_TX: J3.5, U6.3 (2Y)
CGND: D10.A, D11.A, MGT1.P$1, MGT2.P$1, MGT3.P$1, MGT4.P$1, R34.2, R181.2, R182.2, R183.2, R184.2, R185.2, R186.2, X1.CGND1 (SGND1), X1.CGND2 (SGND2), X1.CGND3 (SGND3), X1.CGND4 (SGND4), X1.CGND5 (SGND5), X1.CGND6 (SGND6), X3.CGND1, X3.CGND2, X3.CGND3, X3.CGND4, X3.CGND5, X3.CGND6, X4.S1 (SHD1), X4.S2 (SHD2), X12.1
CLKOUT2: C2.2, J4.18 (EMU3), U1.B4 (XDMA_EVENT_INTR1)
CRS: ER124.1, U8.14 (CRS)
EEPROM_WP: J1.1, U1.M2 (EEPROM_WP)
EHRPWM1A: U1.P12 (GPMC_A2)
EHRPWM1B: U1.T13 (GPMC_A3)
EHRPWM2A: U1.T4 (GPMC_AD8)
EHRPWM2B: U1.P5 (GPMC_AD9)
EMMC_RSTN: R19.2, R52.1, U7.K5 (RST#)
EMMC_VCCI: C13.2, U7.C2 (VDDI)
GND: C1.1, C2.1, C3.2, C6.1, C11.-, C13.1, C14.2, C15.2, C16.1, C17.1, C18.1, C19.1, C20.1, C21.2, C22.2, C41.2, C42.2, C79.2, C85.2, C87.2, C88.2, C93.2, C94.-, C95.2, C96.2, C97.2, D13.A, EC30.2, EC31.2, EC32.2, EC33.2, EC34.2, EC35.2, EC36.2, EC37.2, EC38.2, EC39.2, EC40.2, EC41.2, EC42.2, ER101.2, ER102.2, ER103.2, ER104.2, ER115.1, ER117.1, ER120.1, ER128.1, ER129.2, G1.-, IC1.3 (GND), IC1.5 (EN), IC1.6 (GND), IC2.8 (GND), IC3.GND, IC4.8 (GND), IC4.15 (INH), IC5.3 (E), IC5.4 (F), IC5.5 (G), IC5.6 (H), IC5.8 (GND), IC5.15 (INH), J1.2, J2.2, J3.1, J4.4 (TDIS), J4.8 (GND1), J4.10 (GND2), J4.12 (GND3), J4.16 (GND4), J4.20 (GND5), J6.2, R1.2, R2.2, R3.2, R6.1, R9.2, R17.1, R18.1, R26.2, R27.1, R34.1, R35.2, R36.2, R37.2, R38.2, R39.1, R53.1, R54.1, R55.1, R56.1, R57.1, R58.1, R59.1, R60.1, R61.1, R62.1, R63.1, R64.1, R65.1, R66.1, R67.1, R68.1, R158.2, R281.1, R282.1, R283.1, R284.1, R285.1, R286.1, R287.1, R288.1, R291.1, R292.1, R293.1, R294.1, S1.2, S1.4, S2.1, S2.3, TP8.P$1, U1.D8 (DGND), U1.D9 (DGND), U1.E5 (DGND), U1.E6 (DGND), U1.E7 (DGND), U1.E8 (DGND), U1.E9 (DGND), U1.E10 (DGND), U1.E11 (DGND), U1.E12 (DGND), U1.F5 (DGND), U1.F12 (DGND), U1.G5 (DGND), U1.G12 (DGND), U1.H4 (DGND), U1.H5 (DGND), U1.H12 (DGND), U1.H13 (DGND), U1.J4 (DGND), U1.J5 (DGND), U1.J12 (DGND), U1.J13 (DGND), U1.K5 (DGND), U1.K12 (DGND), U1.L5 (DGND), U1.L12 (DGND), U1.M5 (DGND), U1.M6 (DGND), U1.M7 (DGND), U1.M8 (DGND), U1.M9 (DGND), U1.M10 (DGND), U1.M11 (DGND), U1.M12 (DGND), U1.N8 (DGND), U1.N9 (DGND), U2.4 (GND), U3.3 (GND), U4.1 (GND), U6.1 (*1OE), U6.4 (GND), U7.C4 (VSSQ1), U7.E7 (VSS1), U7.G5 (VSS2), U7.H10 (VSS3), U7.K8 (VSS4), U7.N2 (VSSQ2), U7.N5 (VSSQ3), U7.P4 (VSSQ4), U7.P6 (VSSQ5), U8.33 (GND_EP), U16.2 (GND), U16.5 (TESTL), U16.6 (XTAMPER), U16.9 (GND), U16.18 (PIRQ#), U16.19 (ATEST), U16.20 (TWI_WAKEUP#), U16.21 (ATEST), U16.23 (GND), U16.24 (ATEST), U16.32 (GND), U21.4 (VSS), U25.3 (GND1), U27.2 (GND), X1.GND, X3.6 (VSS), X3.GND, X4.8 (D_GND), X7.2
GPIO0_18: RTC1.3 (SQW), U1.J15 (USB0_DRVVBUS)
GPIO0_26: U1.R5 (GPMC_AD10)
GPIO0_27: U1.T5 (GPMC_AD11)
GPIO1_12: IC2.2 (I2), U1.P6 (GPMC_AD12)
GPIO1_13: IC2.3 (I3), U1.R6 (GPMC_AD13)
GPIO1_14: IC2.4 (I4), U1.T6 (GPMC_AD14)
GPIO1_15: IC2.5 (I5), U1.P7 (GPMC_AD15)
GPIO1_16: U1.T12 (GPMC_A0), U25.6 (!RE), U25.7 (DE)
GPIO1_28: U1.N14 (GPMC_BEN1)
GPIO1_29: U1.P3 (GPMC_CSN0)
GPIO2_1: U1.T7 (GPMC_CLK)
GPIO3_21: IC2.1 (I1), U1.C4 (MCASP0_AHCLKX)
HDMICLK_DISN: U1.T16 (GPMC_A11)
HDMI_INT: U1.T15 (GPMC_A9)
I2C0_SCL: R12.1, U1.C10 (I2C0_SCL), U1.D10 (PMIC_SCL), U16.29 (SM_CLK)
I2C0_SDA: R13.1, U1.C11 (I2C0_SDA), U1.D11 (PMIC_SDA), U16.30 (SM_DAT)
I2C2_SCL: R95.1, RTC1.8 (SCL), U1.A10 (UART1_RTSN)
I2C2_SDA: R96.1, RTC1.7 (SDA), U1.B10 (UART1_CTSN)
ISO_GND: C43.2, C44.2, C45.2, C46.2, D14.A, D15.A, L3.5, U25.9 (GND2_2), U25.15 (GND2), U26.2 (GND), X13.3
ISO_VIN: C44.1, C45.1, D16.C, D17.C, U26.1 (VIN), U26.3 (ON/!OFF)
JTAG_EMU0: J4.13 (EMU0), R40.1, U1.E2 (EMU0)
JTAG_EMU1: J4.14 (EMU1), R41.1, U1.E3 (EMU1)
JTAG_TCK: J4.9 (TCKRTN), J4.11 (TCK), U1.D1 (TCK)
JTAG_TDI: J4.3 (TDI), U1.C1 (TDI)
JTAG_TDO: J4.7 (TDO), U1.C2 (TDO)
JTAG_TMS: J4.1 (TMS), U1.D2 (TMS)
JTAG_TRSTN: J4.2 (TRSTN), R39.2, U1.D3 (TRSTN)
LCD_DATA0: J8.9, R68.2, R85.1, U1.G3 (LCD_DATA0)
LCD_DATA1: J8.10, R67.2, R84.1, U1.G2 (LCD_DATA1)
LCD_DATA2: J8.7, R66.2, R69.1, R83.1, U1.G1 (LCD_DATA2)
LCD_DATA3: J8.8, R65.2, R82.1, U1.H3 (LCD_DATA3)
LCD_DATA4: J8.5, R64.2, R81.1, U1.H2 (LCD_DATA4)
LCD_DATA5: J8.6, R63.2, R80.1, U1.H1 (LCD_DATA5)
LCD_DATA6: J8.3, R62.2, R79.1, U1.J3 (LCD_DATA6)
LCD_DATA7: J8.4, R61.2, R78.1, U1.J2 (LCD_DATA7)
LCD_DATA8: J8.1, R60.2, R77.1, U1.J1 (LCD_DATA8)
LCD_DATA9: J8.2, R59.2, R76.1, U1.K3 (LCD_DATA9)
LCD_DATA10: J7.10, R58.2, R75.1, U1.K2 (LCD_DATA10)
LCD_DATA11: J7.8, R57.2, R74.1, U1.K1 (LCD_DATA11)
LCD_DATA12: J7.9, R56.2, R73.1, U1.L3 (LCD_DATA12)
LCD_DATA13: J7.7, R55.2, R72.1, U1.L2 (LCD_DATA13)
LCD_DATA14: J7.5, R54.2, R71.1, U1.L1 (LCD_DATA14)
LCD_DATA15: J7.6, R53.2, R70.1, U1.M3 (LCD_DATA15)
LCD_DE: J7.4, R28.2
LCD_HSYNC: J7.3, R29.2
LCD_PCLK: J7.2, R31.2
LCD_VSYNC: J7.1, R30.2
LDO_PGOOD: TP22.TP, U1.N4 (PMIC_LDO_PGOOD), U1.N5 (RTC_PWRONRSTN)
MDIO_CLK: U1.D13 (MDC), U8.17 (MDC)
MDIO_DATA: ER105.2, U1.E13 (MDIO), U8.16 (MDIO)
MII1_COL: ER123.2, U1.F15 (MII1_COL)
MII1_CRS: ER124.2, U1.F14 (MII1_CRS)
MII1_RXCLK: ER116.2, U1.E16 (MII1_RX_CLK)
MII1_RXD0: ER113.2, U1.E14 (MII1_RXD0)
MII1_RXD1: ER112.2, U1.D16 (MII1_RXD1)
MII1_RXD2: ER111.2, U1.D15 (MII1_RXD2)
MII1_RXD3: ER110.2, U1.D14 (MII1_RXD3)
MII1_RXDV: ER114.2, U1.F16 (MII1_RX_DV)
MII1_RXERR: ER118.2, U1.E15 (MII1_RX_ER)
MII1_TXCLK: ER119.2, U1.H16 (MII1_TX_CLK)
MII1_TXD0: U1.H15 (MII1_TXD0), U8.22 (TXD0)
MII1_TXD1: U1.H14 (MII1_TXD1), U8.23 (TXD1)
MII1_TXD2: U1.G16 (MII1_TXD2), U8.24 (TXD2)
MII1_TXD3: U1.G15 (MII1_TXD3), U8.25 (TXD3)
MII1_TXEN: U1.G14 (MII1_TX_EN), U8.21 (TXEN)
MMC0_CD: J4.19 (EMU4), R92.1, U1.C14 (SPI0_CS1), X3.CD (CD#)
MMC0_CLK: R88.1, U1.B15 (MMC0_CLK), X3.5 (CLK)
MMC0_CMD: R87.1, U1.B16 (MMC0_CMD), X3.3 (CMD/DI)
MMC0_DAT0: R89.1, U1.A16 (MMC0_DAT0), X3.7 (DAT0/DO)
MMC0_DAT1: R90.1, U1.A15 (MMC0_DAT1), X3.8 (DAT1)
MMC0_DAT2: R86.1, U1.C16 (MMC0_DAT2), X3.1 (DAT2)
MMC0_DAT3: R91.1, U1.C15 (MMC0_DAT3), X3.2 (DAT3/CS)
MMC1_CLK: R51.1, U1.P2 (GPMC_CSN1), U7.M6 (CLK)
MMC1_CMD: R50.1, U1.P1 (GPMC_CSN2), U7.M5 (CMD)
MMC1_DAT0: R42.1, U1.R3 (GPMC_AD0), U7.A3 (DAT0)
MMC1_DAT1: R43.1, U1.R2 (GPMC_AD1), U7.A4 (DAT1)
MMC1_DAT2: R44.1, U1.R1 (GPMC_AD2), U7.A5 (DAT2)
MMC1_DAT3: R45.1, U1.T3 (GPMC_AD3), U7.B2 (DAT3)
MMC1_DAT4: R46.1, U1.T2 (GPMC_AD4), U7.B3 (DAT4)
MMC1_DAT5: R47.1, U1.T1 (GPMC_AD5), U7.B4 (DAT5)
MMC1_DAT6: R48.1, U1.P4 (GPMC_AD6), U7.B5 (DAT6)
MMC1_DAT7: R49.1, U1.R4 (GPMC_AD7), U7.B6 (DAT7)
MODE2: ER99.2, ER123.1, U8.15 (COL/CRS_DV/MODE2)
unnamed: R10.1, X1.VBUS
unnamed: D7.2 (C), R38.1
unnamed: J6.1, R69.2
unnamed: R8.2, U4.2 (RESET#)
unnamed: TP1.TP, U1.F4 (VDDS_DDR)
unnamed: D2.2 (C), R3.1
unnamed: D1.2 (C), R26.1
unnamed: R15.2, R20.1, U5.1 (REF)
unnamed: Q1.B, R21.1, U5.2 (CATHODE)
unnamed: D6.2 (C), R37.1
unnamed: D5.2 (C), R36.1
unnamed: J11.1, J12.1, R181.1, R214.1, X9.1
unnamed: D4.2 (C), R35.1
unnamed: D10.C, U27.7 (CANH), X12.3
unnamed: D11.C, U27.6 (CANL), X12.2
unnamed: TP2.TP, U1.G4 (VDD_CORE)
unnamed: TP3.TP, U1.F13 (VDD_MPU)
unnamed: TP4.TP, U1.G13 (VDDS_PLL)
unnamed: R4.1, U1.A4 (XDMA_EVENT_INTR0)
unnamed: R161.2, U21.3 (W#)
unnamed: J51.1, J52.1, R185.1, R254.1, X11.1
unnamed: R160.2, U21.7 (HOLD#)
unnamed: R19.1, U1.R13 (GPMC_A4)
unnamed: R11.1, S1.1, S1.3
unnamed: C151.1, J53.1, R254.2, U$6.3 (+IN)
unnamed: J51.2, R251.2
unnamed: R5.1, U3.4 (Y)
unnamed: J53.2, R253.1
unnamed: J52.2, R252.1
unnamed: R1.1, U1.M16 (RTC_KALDO_ENN)
unnamed: J61.1, J62.1, R186.1, R264.1, X11.3
unnamed: D8.2 (C), R2.1
unnamed: EC40.1, ER122.2, X4.4 (TCT), X4.5 (RCT)
unnamed: D21.2 (C), R171.1
unnamed: D23.2 (C), R173.1
unnamed: D22.2 (C), R172.1
unnamed: IC2.16 (O1), K1.2, R171.2
unnamed: IC2.15 (O2), K2.2, R172.2
unnamed: C161.1, J63.1, R264.2, U$6.5 (+IN)
unnamed: D24.2 (C), R174.1
unnamed: D25.2 (C), R175.1
unnamed: J11.2, R211.2
unnamed: J12.2, R212.1
unnamed: J61.2, R261.2
unnamed: J63.2, R263.1
unnamed: J62.2, R262.1
unnamed: IC2.13 (O4), K4.2, R174.2
unnamed: IC2.12 (O5), K5.2, R175.2
unnamed: IC2.14 (O3), K3.2, R173.2
unnamed: J13.2, R213.1
unnamed: J21.1, J22.1, R182.1, R224.1, X9.3
unnamed: C121.1, J23.1, R224.2, U$3.5 (+IN)
unnamed: G1.+, RTC1.6 (VBAT)
unnamed: IC4.6 (H), R288.2, S12.8
unnamed: C111.1, J13.1, R214.2, U$3.3 (+IN)
unnamed: J21.2, R221.2
unnamed: J23.2, R223.1
unnamed: J22.2, R222.1
unnamed: D9.2 (C), R9.1
unnamed: C4.1, R94.1
unnamed: J31.1, J32.1, R183.1, R234.1, X10.1
unnamed: C131.1, J33.1, R234.2, U$5.3 (+IN)
unnamed: J31.2, R231.2
unnamed: J33.2, R233.1
unnamed: R31.1, U1.F1 (LCD_PCLK)
unnamed: J32.2, R232.1
unnamed: R30.1, U1.F3 (LCD_VSYNC)
unnamed: J41.1, J42.1, R184.1, R244.1, X10.3
unnamed: C141.1, J43.1, R244.2, U$5.5 (+IN)
unnamed: J41.2, R241.2
unnamed: J43.2, R243.1
unnamed: C4.2, IC1.4 (FB), R17.2, R93.1
unnamed: J42.2, R242.1
unnamed: D14.C, F3.2, U25.11 (Y), U25.14 (A)
unnamed: D15.C, F4.2, U25.12 (Z), U25.13 (B)
unnamed: F3.1, X13.1
unnamed: F4.1, X13.2
unnamed: R29.1, U1.F2 (LCD_HSYNC)
unnamed: C43.1, C46.1, U25.16 (VCC2), U26.5 (VOUT)
unnamed: R28.1, U1.E1 (LCD_AC_BIAS_EN)
unnamed: D16.A, L3.6
unnamed: D17.A, L3.4
unnamed: L3.1, U25.1 (D1)
unnamed: L3.3, U25.2 (D2)
unnamed: IC4.5 (G), R287.2, S12.4
unnamed: IC4.4 (F), R286.2, S12.2
unnamed: IC4.3 (E), R285.2, S12.1
unnamed: IC4.14 (D), R284.2, S11.8
unnamed: IC4.13 (C), R283.2, S11.4
unnamed: IC4.12 (B), R282.2, S11.2
unnamed: IC4.11 (A), R281.2, S11.1
unnamed: IC5.11 (A), R291.2, S13.8
unnamed: IC5.12 (B), R292.2, S13.7
unnamed: IC5.13 (C), R293.2, S13.6
unnamed: IC5.14 (D), R294.2, S13.5
unnamed: IC4.10 (SER), IC5.9 (QH)
unnamed: ER126.1, U8.5 (XTAL1/CLKIN)
unnamed: EC42.1, ER125.2, ER126.2, Y7.P$2 (2)
unnamed: EC41.1, ER127.2, Y7.P$1 (1)
unnamed: ER125.1, ER127.1, U8.4 (XTAL2)
unnamed: ER128.2, U8.32 (RBIAS)
unnamed: ER129.1, U8.18 (NINT/TXER/TXD4)
unnamed: ER120.2, U8.2 (LED2/!INTSEL), X4.A1 (YELA)
unnamed: U8.3 (LED1/REGOFF), X4.C2 (GRNA)
unnamed: EC33.1, EC35.1, U8.6 (VDDCR)
unnamed: ER115.2, X4.C1 (YELC)
unnamed: ER117.2, X4.A2 (GRNC)
OSC0_GND: C7.2, C12.2, U1.N15 (OSC0_GND)
OSC0_IN: C12.1, R32.2, U1.P16 (OSC0_IN), Y2.P$2 (2)
OSC0_OUT: C7.1, R32.1, U1.N16 (OSC0_OUT), Y2.P$1 (1)
OSC1_GND: RTC1.5 (GND), U1.B5 (OSC1_GND)
OSC1_IN: R24.2, RTC1.1 (32KHZ), U1.A6 (OSC1_IN)
OSC1_OUT: U1.A5 (OSC1_OUT)
PMIC_INT: TP24.TP, U1.D4 (EXTINTN), U1.E4 (PMIC_NINT)
PMIC_MUX_IN: R18.2, R22.1, U1.N13 (PMIC_MUX_IN)
PMIC_NRESET: J2.1, U1.M13 (PMIC_NRESET)
PMIC_NWAKEUP: TP23.TP, U1.L4 (PMIC_NWAKEUP), U1.M4 (EXT_WAKEUP)
PMIC_PGOOD: U1.N12 (PMIC_PGOOD), U1.P11 (PWRONRSTN), U3.2 (A)
PWR_BUT: S2.2, S2.4, U1.T11 (PMIC_PB_IN)
PWR_EN: TP21.TP, U1.N10 (PMIC_POWER_EN), U1.N11 (PMIC_PWR_EN)
RESET: R5.2, R11.2, U4.3 (MR#)
RTC_RST: RTC1.4 (RST), U1.R12 (GPMC_A1)
RXD0: ER98.2, ER113.1, U8.11 (RXD0/MODE0)
RXD1: ER100.2, ER112.1, U8.10 (RXD1/MODE1)
RXD2: ER103.1, ER111.1, U8.9 (RXD2/RMIISEL)
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

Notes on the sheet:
Power & Reset
Clocks, Analog & USB
SiP Interfaces
Boot configuration
eMMC
LCD Headers
Micro SD card slot
User LEDs
JTAG Header
Beaglebone Ethernet
USB Client
SiP GND & Misc
1/12
3/12
2/12
4/12
5/12
6/12
9/12
8/12
7/12
Mounting Holes
Fiducials
User Config Switches
External Real Time Clk
TPM
Secure NOR Boot Flash
Notes
12/12
11/12
10/12
Power Supply
Relay Outputs
Universal Inputs
RS-485 Interface
CAN Interface

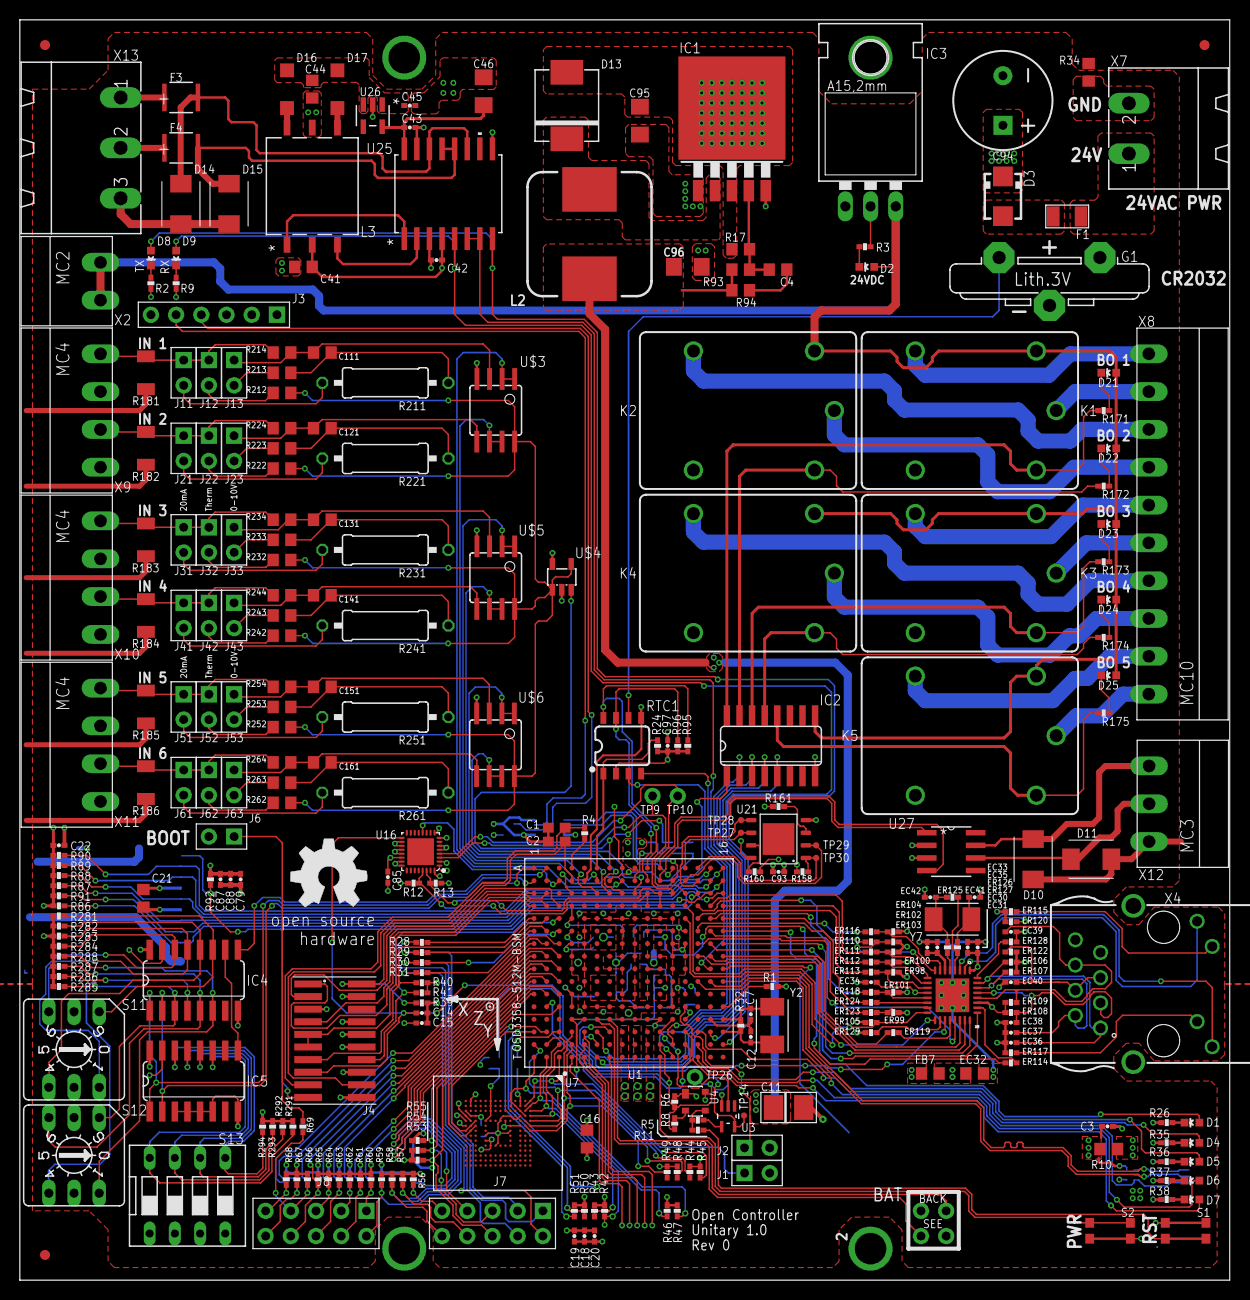
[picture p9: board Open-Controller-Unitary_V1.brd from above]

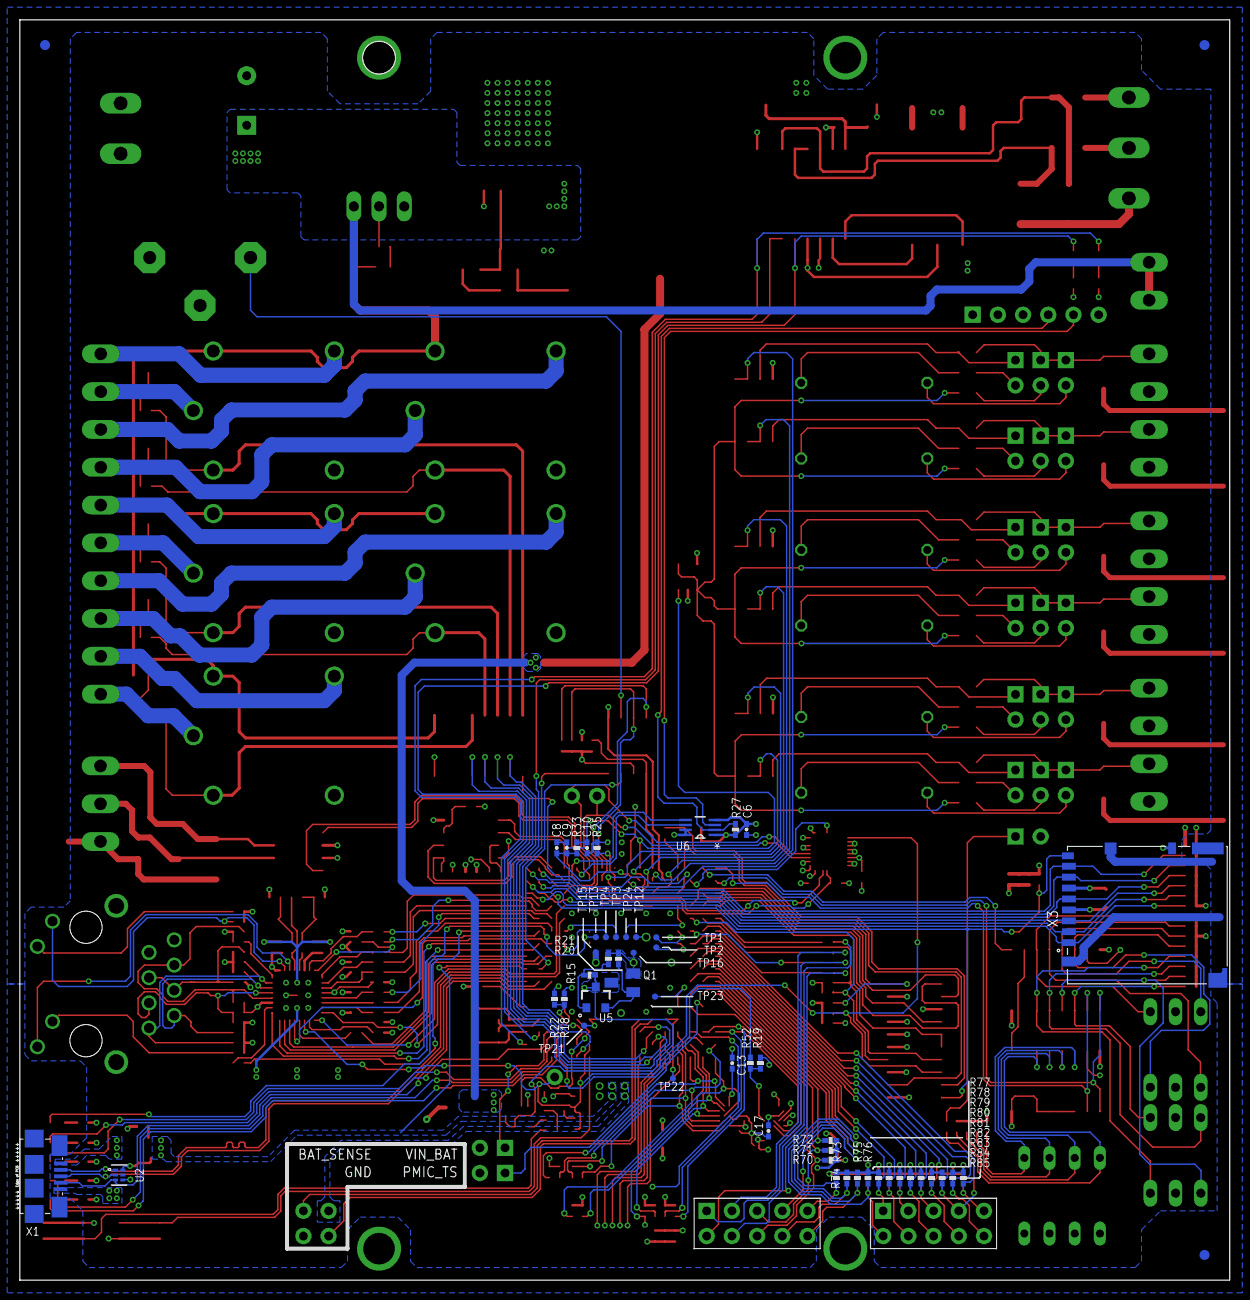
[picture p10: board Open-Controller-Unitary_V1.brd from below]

Board: 4 copper layers, 121.9 x 127.0 mm, 364 parts (53 on the bottom side), 282 nets.

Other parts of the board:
U$2: XYZ-LABEL
U$8: OSHW_8MM

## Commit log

2019-12-04 v2.1 Prototype - Final
    [Open-Source_Control_Unitary_V2_R1.brd]
2020-10-21 Add files via upload
    adding PRU UART option
    [Open-Source_Control_V2_R2.brd, Open-Source_Control_V2_R2.sch]
2024-06-23 Add files via upload
    Fixed CAN1_TXD CAN1_RXD criss-crossed
    [Open-Source_Control_V3_R0.brd, Open-Source_Control_V3_R0.sch]
2024-06-24 Added 6th B-output BO_6
    Added 6th B-output BO_6 to expansion header. Now a total of 6 relay outputs are possible
    [Open-Source_Control_V3_R0.brd, Open-Source_Control_V3_R0.sch]

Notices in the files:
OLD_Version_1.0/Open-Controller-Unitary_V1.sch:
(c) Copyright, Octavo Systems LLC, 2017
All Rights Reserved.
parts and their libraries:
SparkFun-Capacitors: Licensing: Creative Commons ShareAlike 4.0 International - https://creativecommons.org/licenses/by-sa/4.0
